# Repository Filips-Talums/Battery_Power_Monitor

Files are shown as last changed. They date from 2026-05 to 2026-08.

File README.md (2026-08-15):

# Supply_Power_Monitor

## Overview

Battery_Power_Monitor is an ESP32-based DC inline power monitor designed to measure voltage, current, and power while a DC source powers an external load.

The system is designed to support a wide range of DC input sources from 6 V to 12 V and aims to act as a compact monitoring tool for electronics development and testing.

---

## Project Goals

Through this project I aim to learn:

- PCB design using KiCad
- Circuit testing and calibration
- ESP32 microcontroller development
- Embedded systems programming using C++
- Professional project documentation using GitHub
- Power monitoring and sensor integration

---

## Components Used

- ESP32 Development Board
- INA226 Power Monitoring Sensor
- 128x64 I2C OLED Display
- 6 V buck-boost converter module for powering the ESP32 from a 6–12 V input
- Screw Terminals
- Electrolytic and Ceramic Capacitors
- Fuse Protection

---

## How It Works

An external DC power source between 6 V and 12 V is connected through screw terminals.

The input power is split into two sections:

- A regulated 6 V supply powers the ESP32 and OLED display
- The main power line passes through the INA226 current and voltage sensor before reaching the external load

The INA226 measures:

- Bus Voltage
- Current Draw
- Power Consumption

The ESP32 processes this data and displays the measured values on the OLED screen.

The device is intended to help monitor power usage, diagnose faults, and test small electronics projects safely.

---

## System Diagram

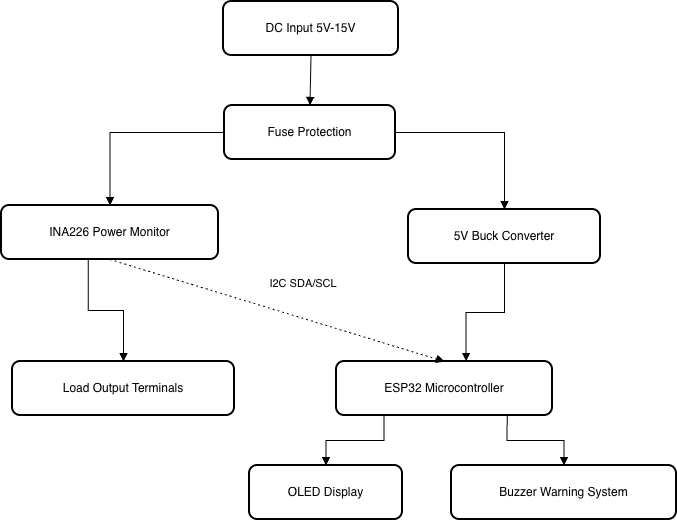
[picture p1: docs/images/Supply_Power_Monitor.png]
System Diagram


### Power Flow

```text
DC Input (6 V - 12 V)
        │
        ├──→ LM2596S Buck Converter (5 V)
        │          │
        │          └──→ ESP32 ──→ OLED Display
        │                        └──→ Buzzer Warning
        │                        └──→ LED Warning
        └──→ Fuse Protection
                   │
                   └──→ INA226 Power Monitor
                                │
                                └──→ Load Output
```
## Current Status

The breadboard prototype is now working. The ESP32 successfully reads bus voltage and shunt voltage from the INA226 power monitoring sensor and displays voltage, current, and power on the OLED display.

Initial voltage calibration has been completed using a multimeter. The raw INA226 bus voltage reading was found to be consistently higher than the multimeter reading, so a software correction factor was applied.

Current calculation has been implemented using the INA226 shunt voltage and the R100 0.1 Ω shunt resistor. Initial current testing has been carried out using resistor loads and a multimeter. The monitor initially under-read current slightly, so a current correction factor was added in software. Further load testing with higher-current loads is still planned.

* Project requirements defined
* Main components selected
* System block diagram completed
* PlatformIO project created
* INA226 integrated with the ESP32
* OLED display integrated and tested
* Live voltage, current and power measurements displayed
* Voltage readings calibrated against a multimeter
* Current readings tested and calibrated using multiple resistive loads
* Breadboard prototype completed and tested
* Circuit transferred from breadboard to perfboard
* LM2596 buck converter configured to provide a regulated 5 V supply
* Schottky diode and polyfuse protection added
* LED and buzzer fault indicators added
* ESP32 mounted using removable female headers
* Initial perfboard wiring faults identified and repaired
* Perfboard prototype powered and operating successfully
* Breadboard and perfboard software versions organised separately
* Manufacturing process, testing and troubleshooting documented
* Project images added to the documentation

## Project Images

### Top View — Arduino Load at 8.76 V

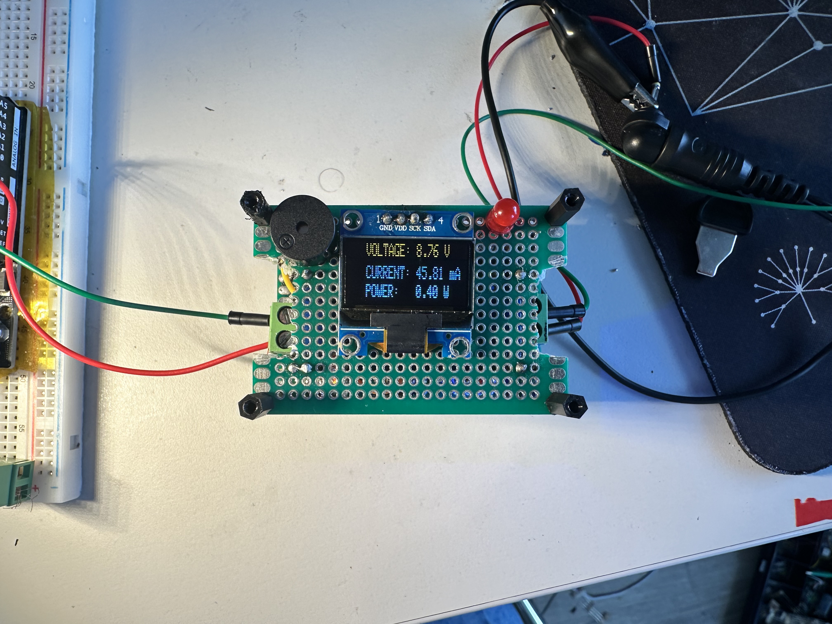
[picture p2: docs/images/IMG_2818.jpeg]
Top view of the power monitor testing an Arduino load at 8.76 V


### Isometric View — Power Monitor and Arduino Load

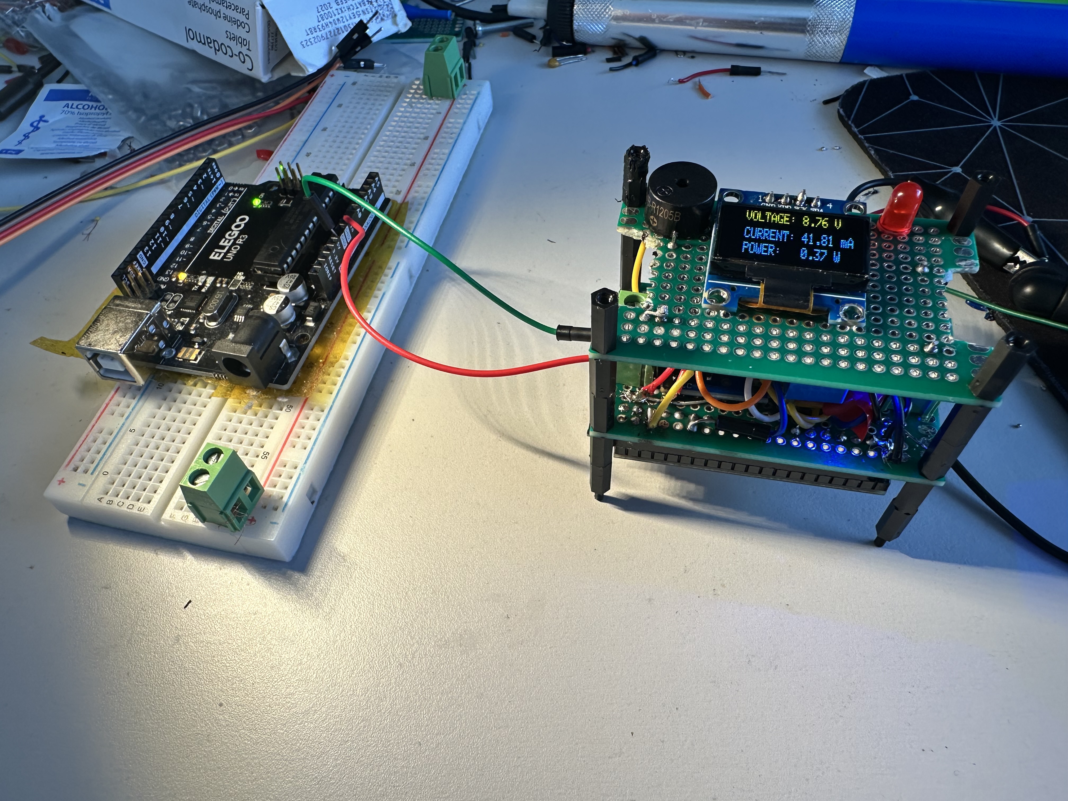
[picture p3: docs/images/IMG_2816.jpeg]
Isometric view showing the power monitor and Arduino load


### Side View of the Device

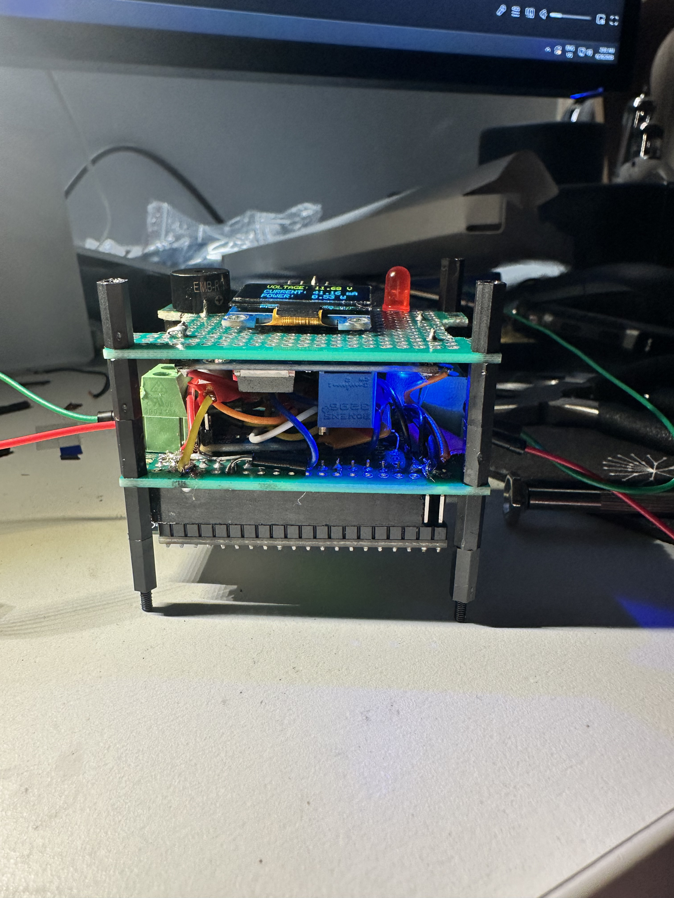
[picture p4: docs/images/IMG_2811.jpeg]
Side view of the completed power monitor prototype


### Isometric View — Arduino Load at 11.68 V

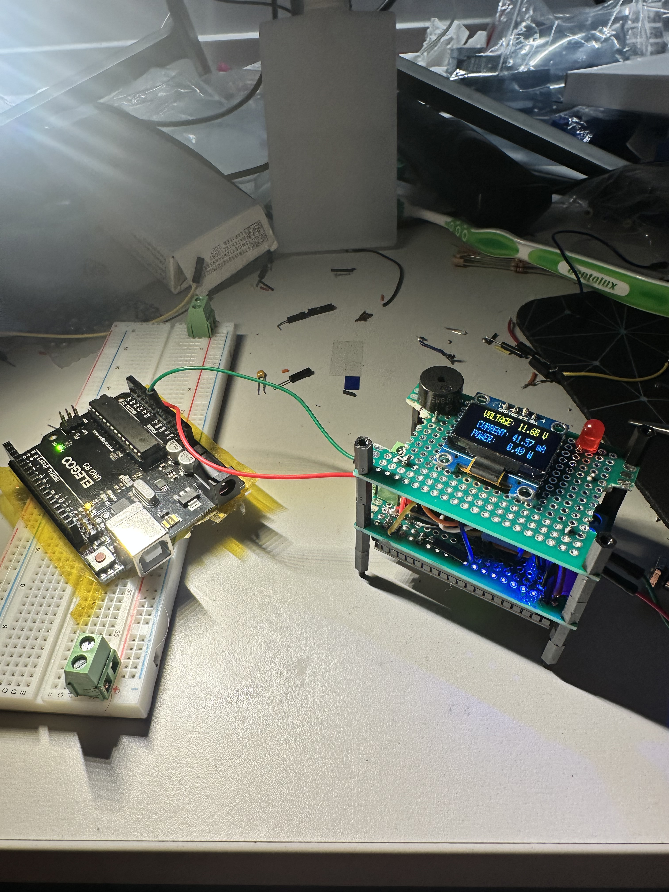
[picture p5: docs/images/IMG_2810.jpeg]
Isometric view of the Arduino and power monitor displaying 11.68 V


### Isometric View — Arduino Load at 8.78 V Input

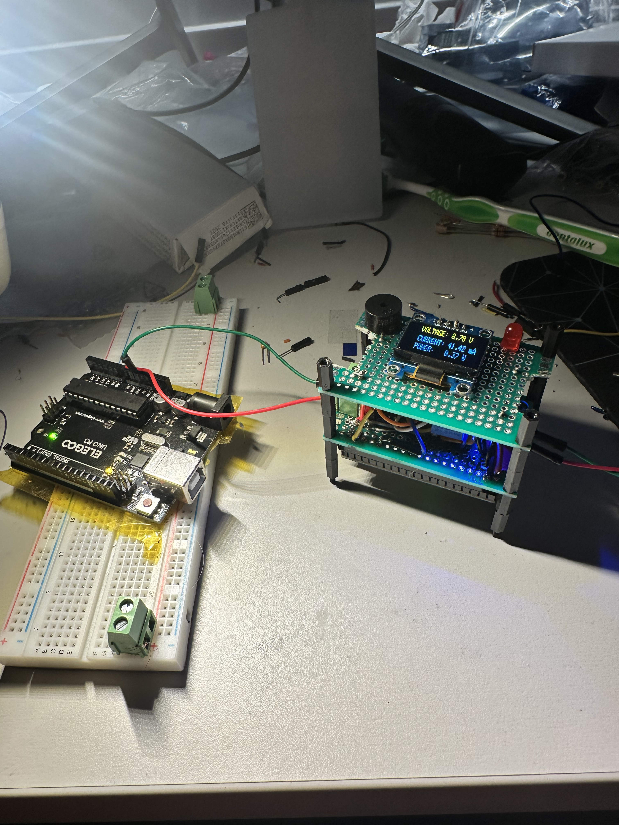
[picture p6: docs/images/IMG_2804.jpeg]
Isometric view of the Arduino load and power monitor at an 8.78 V input


## Next Steps

* Complete extended testing with higher-current loads
* Confirm the 2 A warning system under a controlled load
* Design a custom PCB in KiCad
* Add suitable connectors and component footprints
* Design or manufacture an enclosure
* Perform final accuracy, thermal and reliability testing

## Software

- [Breadboard Prototype V1](software/breadboard-prototype-v1/)

- [Perfboard Prototype V2](software/perfboard-prototype-v2/)

## Project Documentation

- [Design Process](Design_Process.md)
- [Hardware Files](hardware/)
- [Software](software/)
- [Examples](examples/)
- [Learning Notes](docs/learning/)

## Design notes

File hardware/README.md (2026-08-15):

# Hardware

- [KiCad](kicad/) contains PCB design sources, earlier board versions, manufacturing outputs, and recovery material.
- [Schematics](schematics/) contains exported circuit diagrams.
- [Datasheets](datasheets/) contains component reference documents used by the project.

All historical design and manufacturing files are retained so that earlier project stages remain reproducible.

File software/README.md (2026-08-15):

# Software

The software is kept in project-stage folders so working historical checkpoints remain available:

- [Breadboard prototype V1](breadboard-prototype-v1/) is the stable calibrated breadboard firmware.
- [Perfboard prototype V2](perfboard-prototype-v2/) is the firmware associated with the perfboard build.
- [`platformio/`](platformio/) contains the earlier `Supply_Power_Monitor` and `Supply_Power_Monitor_TEST` PlatformIO projects.
- [`pseudocode.txt`](pseudocode.txt) contains the early software design outline.

Each firmware project is self-contained and should be opened from its own directory in PlatformIO.

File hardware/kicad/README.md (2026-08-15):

# KiCad Designs

This directory preserves the project's KiCad design history and manufacturing files:

- `Power_Monitor_V1/` contains the first PCB design.
- `Power_Monitor_V2/` contains the version 2 project, its libraries, 3D model, and tracked recovery material.
- The top-level `Power_Monitor_V2.1.kicad_*` files contain the later version 2.1 board project files.
- `PCB_V2_PRINTING/` and `PCB_V2_PRINTING.zip` contain version 2 manufacturing outputs.

Recovery and historical files are intentionally retained. Open the version matching the project stage you want to inspect.

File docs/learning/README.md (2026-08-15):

# Learning Notes

- [Learning PlatformIO](Learning_PlatformIO.md) records PlatformIO project structure, mock sensor testing, and lessons learned.
- [ESP32 Notes](ESP32_Notes.md) is a placeholder for future ESP32 notes.
- [INA226 Research](INA226_Research.md) is a placeholder for future INA226 research.

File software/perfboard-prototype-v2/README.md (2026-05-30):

# Breadboard Prototype V1 Software

This folder contains the PlatformIO software used for the first working breadboard prototype of the DC inline power monitor.

## Purpose

The software reads bus voltage and shunt voltage from the INA226 power monitoring sensor using the ESP32. Current is calculated manually using the R100 shunt resistor value, and power is calculated using voltage multiplied by current.

The measured voltage, current, and power values are displayed on a 0.96 inch 128x64 I2C OLED display.

## Hardware Used

- ESP32 development board
- INA226 power monitoring module with R100 0.1 Ω shunt resistor
- 0.96 inch 128x64 I2C OLED display
- LM2596S step-down buck converter
- Resistor loads for current testing
- Breadboard wiring

## Features

- Reads INA226 bus voltage
- Reads INA226 shunt voltage
- Calculates current manually using the shunt resistor value
- Calculates power manually using voltage × current
- Displays voltage, current, and power on the OLED display
- Displays low current values in milliamps
- Includes voltage correction based on multimeter calibration
- Includes current correction based on resistor load testing

## Calibration

During voltage testing, the raw INA226 bus voltage reading was consistently higher than the multimeter reading. A software correction factor was applied to make the displayed voltage match the measured voltage more closely.

Current testing was carried out using resistor loads and a multimeter. The monitor initially under-read current slightly, so a current correction factor was added in software.

Current is calculated using:

```text
Current = Shunt Voltage / Shunt Resistance
```

## Current Status

This version is confirmed working on the breadboard prototype. It should be treated as the stable calibrated software checkpoint before adding extra features such as warning outputs, improved display layout, buttons, or PCB-specific changes.

## Next Steps

- Test with higher-current loads
- Add overvoltage warning logic
- Add overcurrent warning logic
- Improve OLED display layout
- Move the circuit from breadboard to a soldered prototype or PCB

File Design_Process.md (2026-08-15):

# Design Process

## 1. Project Aim

The aim of this project is to work as a power monitor between the source voltage and load, being an external project. The monitor will display useful information like the incoming voltage, current and the power the load is taking in. It'll be designed to be compact and be an addition to my electronics workbench where i can use it to create and diagnose, if needed, future projects.

## 2. Problem / Need

When testing small electronics projects, it can be difficult to know how much current the circuit is drawing from the power source. If a project draws more current than expected, it may indicate a wiring fault, short circuit, damaged component, or incorrect design. In many cases, the problem is only noticed after a component becomes hot, behaves incorrectly, or fails completely.

This project is designed to make voltage, current, and power usage visible in real time. By placing the monitor between the power source and the external load, faults can be spotted earlier and diagnosed more quickly. This should reduce the chance of damaging components and make testing small electronics projects safer and easier.

## 3. Design Requirements

### Compact Design

The device should be small enough to be easily stored, carried, and used on a desk or workbench without taking up too much space.

### Stable Physical Design

The device should sit securely on a table during use. It should not be easily knocked over or pulled off the table when wires are connected.

### Easy-to-Read Display

The voltage, current, and power readings should be clearly shown on the OLED display. The user interface should be simple and readable from normal viewing angles while working at a desk.

### Accurate Readings

The device should measure voltage, current, and power with enough accuracy for testing small electronics projects. The readings should be compared against a multimeter during testing to check for error.

### Safety Features

The circuit should include basic protection features such as a fuse or polyfuse to protect against excessive current. Reverse polarity protection should also be considered to reduce the risk of damaging the device if the input is connected incorrectly.

### Quick Usability

The device should be simple to use. The user should be able to connect a power source and external load using screw terminals, power the device on, and quickly view live voltage, current, and power readings.

### 3.1 Input Voltage Range

The device should support a DC input voltage range of **5 V to 12 V**, which suits small electronics projects such as microcontroller circuits, sensors, LEDs, and low-power modules.

A **5 V buck-boost converter** is required to provide a stable 5 V supply for the ESP32 and OLED display, even when the input voltage varies between 5 V and 12 V. This is needed because a standard buck converter may not reliably output 5 V when the input is also 5 V.

If an adjustable buck-boost converter is used, the adjustment screw or control point should be accessible without needing to disassemble the device. This allows the output voltage to be checked or adjusted during setup and maintenance.

### 3.2 Current Range

The first iteration of the power monitor will be designed for small electronics projects with a current range of **0–3 A**. This range is suitable for low-power sensor circuits, microcontroller projects, LED modules, and small single-board computer projects.

A 3 A limit gives more headroom than a 1 A design, as some devices can draw short current spikes during startup or when extra peripherals are connected. For example, a Raspberry Pi or similar board may draw around 1 A or more depending on the connected accessories and workload.

The fuse/polyfuse and INA226 module should be selected so they can safely support the chosen **0–3 A** current range.

### 3.3 Measurements Required

The power monitor is required to display **voltage**, **current**, and **power** in real time.

- **Voltage** should be displayed in volts (V).
- **Current** should be displayed in amps (A), or milliamps (mA) for lower current readings.
- **Power** should be displayed in watts (W).

Power will be calucalted using the measured voltage and current

Power = Current x Voltage

The displayed values should use a suitable number of decimal places so the readings are clear and easy to understand.

### 3.4 Display Requirements

The display should be clear and readable from a normal working distance when the device is being used on a desk or workbench. The readings should also be visible from different viewing angles so the user does not need to position themselves directly above the display.

The user interface should be simple and easy to understand at a glance. Voltage, current, and power readings should be clearly labelled with their correct units, such as V, A, mA, and W.

### 3.5 Safety Requirements

The power monitor should include basic safety features to reduce the risk of damage to the monitor itself and the connected load.

- **Overcurrent protection:** A fuse or resettable polyfuse should be used on the input/load path. This protects the circuit if the external load draws too much current or if a short circuit occurs.

- **Reverse polarity protection:** The input should include protection against the power source being connected the wrong way around. This reduces the risk of damaging the ESP32, INA226, OLED display, and connected load.

- **Overvoltage warning:** The INA226 should be used to detect if the input voltage is above the specified operating range. If the voltage exceeds the safe limit, the ESP32 should display a warning on the OLED screen.

- **Accurate readings:** The device should provide reliable voltage and current readings so the user can identify abnormal current draw or voltage issues before damage occurs.

### 3.6 Size and Usability Requirements

The device should be compact enough for easy storage, transport, and use on a desk or workbench. The target size is approximately the size of three 9 V batteries placed together.

The internal layout should be designed to use space efficiently. Modules may be stacked or arranged in layers inside the chassis if this does not cause overheating, wiring strain, or difficulty accessing key components.

The device should have a stable physical design so it does not move around easily when wires are connected. The weight should be distributed evenly across the chassis to reduce the risk of the device being pulled or knocked off the table during use.

The device should be simple to use and operate as a plug-and-play monitor. It should be powered from the same input source being measured, so no separate external power supply is required for the ESP32, OLED display, or sensor circuit.

## 4. System Overview

### 4.1 Block Diagram

```text
6–12 V DC Input
        │
        ▼
Input Screw Terminals
        │
        ├──→ Buck/Buck-Boost Converter → 5 V → ESP32
        │                                      │
        │                                      ├──→ OLED Display
        │                                      ├──→ LED Warning
        │                                      └──→ Buzzer Warning
        │
        └──→ INA226 Power Sensor → Load Output Terminals → External Load
                         │
                         └── I2C Data → ESP32
```
### 4.2 Power Flow

The DC input first enters the device through the input screw terminals. From there, the input power is split into two paths.

The first path goes to the buck-boost converter. The buck-boost converter provides a stable 5 V output, which is used to power the ESP32, OLED display, LED, and buzzer.

At the same time, the second path goes through the INA226 power monitoring sensor and then continues to the load output terminals. The external load is connected to these output terminals. This allows the INA226 to measure the voltage supplied to the load and the current drawn by the load.

### 4.3 Data Flow

The INA226 power monitoring sensor sends voltage and current readings to the ESP32 using I2C communication. The ESP32 receives this data, processes it in software, and calculates the power value in watts.

The processed data is then sent to the OLED display, where the voltage, current, and power readings are shown to the user. The ESP32 can also control the LED and buzzer based on the measured values, such as activating a warning if the voltage or current goes outside the safe operating range.

## 5. Component Selection

### 5.1 ESP32-WROOM-32E Microcontroller

The ESP32-WROOM-32E was chosen because it gives the project enough processing power and input/output pins for the power monitor without making the design too expensive or complicated.

Compared to an Arduino Uno, the ESP32 has a much faster clock speed and a dual-core processor. This allows it to read data from the INA226 sensor, calculate voltage, current, and power values, update the OLED display, and control the warning LED and buzzer without slowing down.

The ESP32 also uses I2C communication, which is useful because both the INA226 sensor and OLED display can share the same SDA and SCL lines. This reduces wiring and keeps the circuit layout simpler.

Although the project does not currently require wireless features, the built-in WiFi and Bluetooth are useful advantages of the ESP32. They allow the design to be expanded later for data logging, wireless monitoring, or sending readings to a phone or computer.

Overall, the ESP32 was selected because it is low cost, powerful, widely supported, and suitable for real-time monitoring in this project

### 5.2 INA226 Power Monitoring Sensor

The INA226 power monitoring sensor was selected because it is capable of accurately measuring both bus voltage and current while remaining suitable for the scale of this project. It provides a good balance between performance, cost, and simplicity without being unnecessarily complex.

The INA226 can measure bus voltages up to 36 V and current levels depending on the value of the shunt resistor used on the module. The module purchased is rated for up to approximately 3 A, however the exact current limit will depend on the installed shunt resistor. As the specifications of the included shunt resistor were not provided in the product listing, the exact rating will be confirmed once the module arrives.

If required, the shunt resistor can be replaced using soldering equipment to better suit the current range and accuracy requirements of the project.

### 5.3 OLED Display

A 0.96 inch 128x64 I2C OLED display was chosen to show the live voltage, current, and power readings. The display only requires four connections: VCC, GND, SDA, and SCL, making it simple to connect to the ESP32.

The 128x64 resolution provides enough space to display all key readings at the same time, allowing the user to quickly check the power source and load behaviour during testing.

### 5.4 Buck Converter

The input voltage for the project is expected to vary between 5 V and 15 V. As the ESP32 requires a stable 5 V supply, a buck converter is needed to safely reduce and regulate the input voltage. Supplying the ESP32 with a voltage above its rated input could damage the microcontroller and other components.

The LM2596S DC-DC Step-Down Buck Converter Module was selected because it is suitable for the voltage range required in this project while remaining simple to prototype with during development. The module can accept an input voltage between approximately 4.5 V and 40 V and regulate it down to a lower stable output voltage.

The module also includes the main supporting components required for switching regulation already mounted on the PCB, making it easier to integrate into a breadboard prototype before designing a custom PCB later in development.

Although the module is commonly advertised as capable of supplying up to 3 A, this value is treated as a maximum module rating rather than the expected continuous operating current within this project. The ESP32, OLED display, INA226 module, and buzzer require significantly less current, meaning the LM2596S provides sufficient overhead for stable operation.

For this project, the buck converter will be adjusted and verified using a multimeter before connecting the ESP32 to ensure a stable 5 V output is supplied to the circuit safely and reliably.

LM2596 Datasheet:
https://www.ti.com/lit/ds/symlink/lm2596.pdf

### 5.5 Fuse / Polyfuse

A 2 A resettable polyfuse is included to protect the circuit from excessive current caused by faults such as short circuits or wiring mistakes. If the current exceeds the safe operating limit, the polyfuse temporarily increases in resistance to reduce current flow and automatically resets once it cools down.

The polyfuse helps prevent components from failing, PCB traces from burning, and wires from overheating during fault conditions within the circuit.

A 2 A limit was selected as it matches the approximate safe operating range of the LM2596 buck converter used in the project while still providing protection for the circuit.

### 5.6 Capacitors

Capacitors are included to improve voltage stability and reduce electrical noise within the circuit.

A 330 µF electrolytic capacitor is placed in parallel between the input voltage line and ground close to the buck converter input. This helps smooth sudden voltage dips and provides extra stability before the voltage is regulated down to 5 V.

0.1 µF ceramic capacitors are placed between the VCC and GND pins of the ESP32, INA226 module, and OLED display. These capacitors act as local decoupling capacitors and help reduce high-frequency noise caused by switching and sudden current changes.

The electrolytic capacitor is used for bulk voltage smoothing, while the ceramic capacitors are used for high-frequency noise filtering.

### 5.7 Diodes

A diode is placed at the voltage input to protect the circuit if the supply voltage is connected with reverse polarity. If the positive and negative terminals are connected the wrong way around, the diode helps prevent current from flowing through the circuit in the wrong direction, reducing the risk of damage to the buck converter, ESP32, and other components.

A Schottky diode is suitable for this part of the circuit because it has a lower forward voltage drop than a standard silicon diode. This means less voltage is lost across the diode, allowing more of the input voltage to reach the buck converter.

The diode selected should be able to handle the expected input voltage range of up to 15 V and the chosen current range of approximately 2 A.

1N5822 schottky diode chosen

### 5.7 Input and Output Terminals

Screw terminals will be used if a PCB is manufactured as they provide a simple and reliable method of connecting input and output wires. They also allow wires to be easily removed or replaced without soldering, making the system more interchangeable and easier to test.

A 5 mm pitch screw terminal was selected as it is commonly available and capable of handling voltages and currents far above the requirements of this project, typically up to approximately 250 V and 10 A depending on the model used. This provides significant headroom while also allowing the same terminals to be reused in future electronics projects.

## 6. Circuit Design

Inital Circuit Desing:

(fig.0: Image of revision 0 circuit design to be implemented on a breadboard)

Modified with a shared I2C bus between OLED and INA226 Modules

(fig.1: Image of revision 1 circuit design to be implemented on a breadboard)

### 6.1 Input Power Path

The power source is connected to a 1x2 screw terminal. From the positive input terminal, the track passes through the reverse polarity protection diode and the 2 A polyfuse before reaching the VIN+ input of the buck converter. The negative input terminal is connected to the common ground of the circuit.

A 330 µF electrolytic capacitor is placed in parallel between the input voltage line and ground, close to the buck converter input. This helps smooth the input voltage and reduce voltage dips before regulation.

0.1 µF ceramic capacitors are placed between the VCC and GND pins of the ESP32, INA226 module, and OLED display to reduce high frequency electrical noise and interference. These capacitors are positioned as close as possible to the power pins of each component to improve voltage stability and reduce the effect of sudden current spikes within the circuit.

### 6.2 Load Measurement Path

The load measurement path begins at the protected input voltage line after the reverse polarity diode and polyfuse. This line connects to the IN+ pin of the INA226 module. The current then passes through the INA226 shunt resistor and exits through the IN- pin, which connects to the output screw terminal and then to the external load.

The INA226 measures the voltage drop across its shunt resistor to calculate the load current. The VBUS pin is connected to the IN+ side of the measurement path so that the INA226 can also measure the bus voltage being supplied to the load.

The INA226 communicates with the ESP32 using I2C. The SDA and SCL pins connect to ESP32 GPIO 27 and GPIO 14 respectively. The ALERT pin connects to ESP32 GPIO 26 and can be used to trigger a warning if the measured values exceed a set limit.

A possible future improvement would be to use the ALERT pin as part of an automatic protection system. If an overcurrent or fault condition is detected, the ESP32 could use a transistor, MOSFET, or relay driver circuit to disconnect the load as an additional safety feature.

### 6.3 ESP32 Power Supply

The ESP32 receives a stable 5 V supply from the LM2596 buck converter. The 330 µF capacitor is placed near the buck converter input to help smooth voltage dips before regulation.

A stable 5 V supply is required because voltage drops or electrical noise could cause the ESP32 to reset, lose communication with the INA226, cause OLED display errors, or display unreliable readings.

The onboard voltage regulator on the ESP32 development board reduces the 5 V input to 3.3 V. This 3.3 V supply is used to power the INA226 module, OLED display, LED, and suitable low-power output components.

All components share a common ground connection, which provides a common voltage reference for stable communication and accurate measurement through the INA226.

### 6.4 I2C Communication

Figure 0 shows the I2C communication connections between the ESP32, INA226, and OLED display.
The following GPIO outputs are used:     
        
        INA226 + OLED
        - SDA = GPIO19
        - SCL = GPIO18
        
         INA226 
        - ALERT = GPIO26

### 6.5 GPIO Outputs

The following GPIO Outputs used:

         BUZZER
        - Signal Pin = GPIO22
         LED
        - VCC = GPIO23

### 6.6 Display Output

The OLED display is used to show live voltage, current, and power measurements to the user in real time.

The readings are displayed in a simple vertical layout so they can be quickly understood while testing electronics projects on a workbench.

Depending on the measured current range, the displayed units may automatically switch between amps (A) and milliamps (mA) to improve readability and precision.

Example display layout:

```text
|=============================|
|                             |
|       Voltage = 3.3 V       |
|       Current = 1 mA        |
|     PowerDraw = 3.3 mW      |
|                             |
|=============================|
```
### 6.7 Protection and Filtering

The circuit includes several protection and filtering components to improve safety and reliability. A Schottky diode is placed at the voltage input to reduce the risk of damage if the supply is connected with reverse polarity.

A 2 A resettable polyfuse is also used to protect the circuit from excessive current caused by faults such as short circuits or wiring mistakes. If the current becomes too high, the polyfuse increases in resistance and limits current flow until it cools down.

A 330 µF capacitor is placed near the buck converter input to help smooth voltage dips before regulation. Additional 0.1 µF ceramic capacitors are placed close to the ESP32, INA226, and OLED power pins to reduce high frequency noise and improve voltage stability.

## 7. Software Design

[INSERT C++ FILE WHEN FINSIHED]

### 7.1 Sensor Reading

The ESP32 communicates with the INA226 sensor and OLED display using I2C communication. The `Wire.h` library is used to initialise the I2C bus and allow the ESP32 to communicate with connected I2C devices.

I2C allows multiple components to share the same SDA and SCL communication lines. Each device is identified by its own unique I2C address.

For this project, the I2C pins are defined in the I2C Communication section. The bus is initialised using:

```cpp
Wire.begin(19, 18);
```
Commands that will be used to initalise and extract data from the INA226:

- **bool begin()** Used to initalise the class / INA226

- **bool isConnected()** Verifiys if INA226 was foun on the I2C Bus

- **setMaxCurrentShunt()** Sets a Maximum current across the shunt, if exceeeded the Alert pin emmits, later be used to shut of the circuit using a transitor.

- **float getBusVoltage_mV()** Calls the Bus Voltage in mV

- **float getShuntVoltage_mV()** Calls the Shunt Voltage / Voltage drop across the shunt resistor

- **float getCurrent_mA()** Calls the current flwoing through shunt resistor

- **float getPower_mW()** Calls the power which in the library caluclated by (BusV x Current) = Power

- **bool isConversionReady()** Returns a bolean if there is new data ready, used for later iterations of projects as more complicated however more accurate

INA226 library used:
https://github.com/RobTillaart/INA226

### 7.2 Warning / Error Messages

- Overvoltage: If there is a voltage across the shunt resistor > 15 volts, a warning would be displayed on the screen prompting for the Vs to be disconnected before damage occurs.
  
- Undervoltage: If there is a voltage across the shunt resisotr < 5v, a warning would be displayed as the readings can lead to be inaccurate as the esp32then wouldnt be getting the reuiqred voltage as a result

- Overcurrent: If there is over current across shunt resistor above 2 amps itd be displayed on the screen however I do not belive the current would ever reach as the INA226 module would fail as a result of over current howver a fuse would trip if 2 amps is exceeded.

- Sensor Not Found: Using the isConnected() function from the INA226 module, if the module is dead or not connected properly this would show on the screen 

- I2C Communication Error: If communication between the ESP32 and connected I2C devices fails, an error message would be displayed on the OLED screen. This could occur due to loose wiring, incorrect SDA or SCL connections, incorrect device addresses, or a disconnected component. The ESP32 can detect this if the INA226 or OLED no longer responds on the I2C bus.

- Weak Battery: Using (inital voltage - load voltage) / inital voltage * 100 if that is above 12.5 % a warning for a weak battery would be shown

- Measurement Overflow: If the measured voltage or current exceeds the measurable range of the INA226, the readings may become inaccurate or invalid. A warning message would be displayed to indicate that the sensor has exceeded its operating limits and the load or supply should be disconnected immediately.

## 8. Prototype Testing

### 8.2 Buck Converter Test & Calibration

- [Results](docs/testing/buck_converter_test.md)

### 8.3 INA226 Test & Calibration

- [Results](docs/testing/ina226_test.md)

### 8.5 OLED Display Test

- [Results](docs/testing/oled_display_test.md)

Circuit_BB_PreBuzzerLED

### 8.1 Breadboard Test

The completed breadboard prototype marked an important milestone in the project. The earlier component planning and circuit design produced a working result, with the ESP32 and OLED display powering on successfully and showing voltage, current and power data measured by the INA226.

### 10.4 Wiring and Connection Issues

The selected diode had legs that were too thick to fit securely into the breadboard. Crocodile clips were therefore used to connect it temporarily during testing.

Apart from this issue, the breadboard wiring was straightforward and no major connection problems occurred during this stage of prototyping. This allowed the project to progress to the next phase: transferring the circuit onto perfboard.

The buzzer and LED fault indicators were not included in the breadboard prototype because they had initially been overlooked. These features were added later during the perfboard build.

### 10.5 Final Breadboard Design

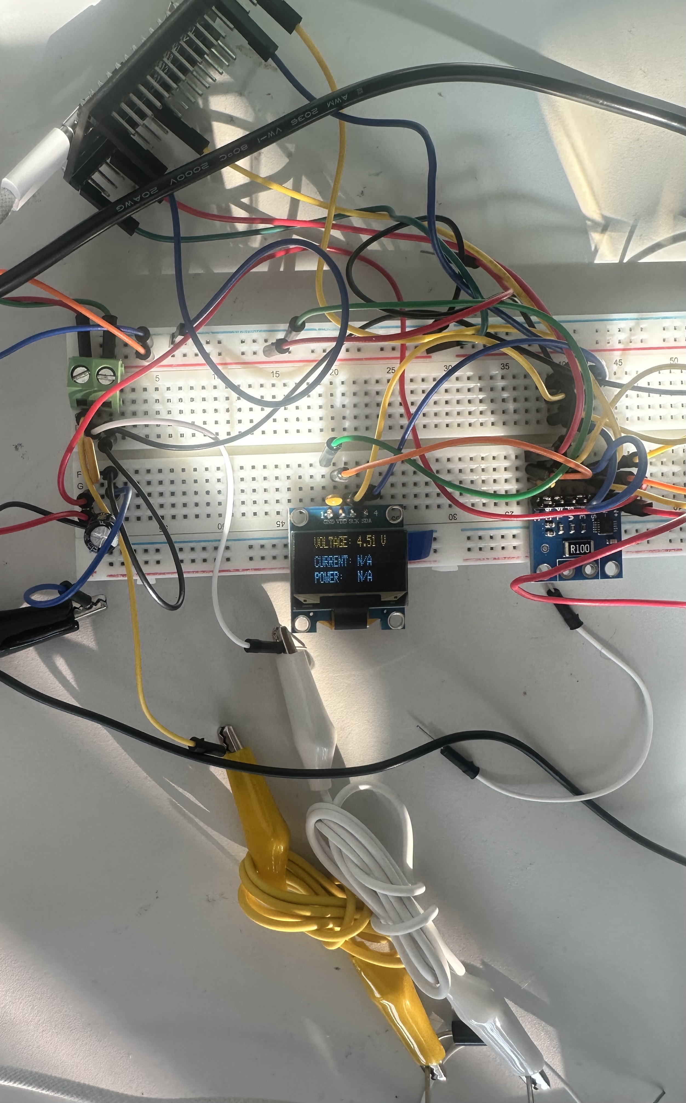
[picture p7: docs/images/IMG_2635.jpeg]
Breadboard build


## 11. Perfboard Prototype

### 11.1 Design

A perfboard kit containing several different board sizes was purchased for the prototype. Initially, the range of sizes appeared useful. However, it quickly became clear that the mounting holes would only align correctly when matching perfboards of the same dimensions were used.

The kit contained five different sizes. Three were too small to accommodate the required header footprint, while another was unnecessarily large. A suitable intermediate size was selected and proved to be a good fit for the final arrangement.

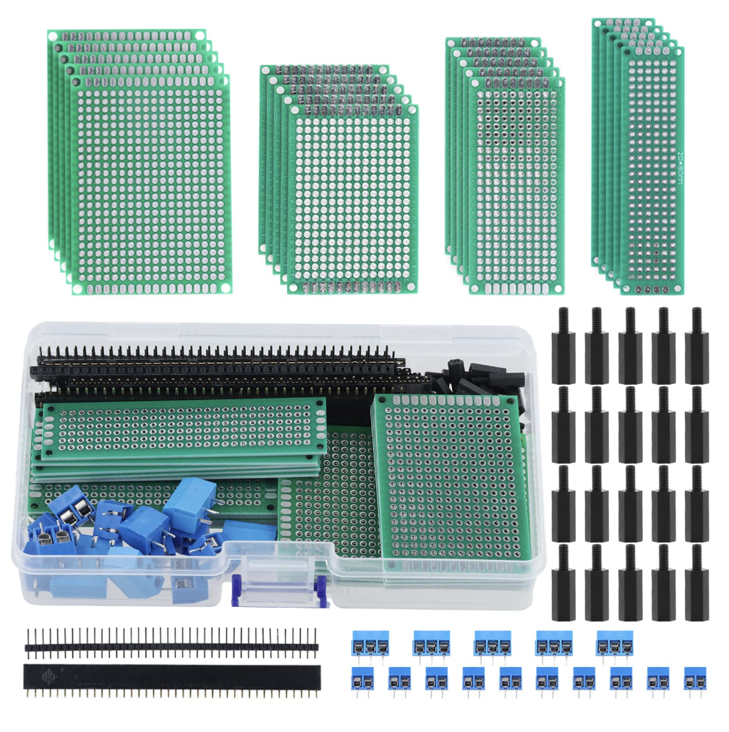
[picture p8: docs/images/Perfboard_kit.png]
Perfboard Kit


The final design used two layers of perfboard mounted together with the nylon hex spacers supplied in the kit. This structure allowed the device to be easily disassembled and reassembled for troubleshooting, repairs and future modifications.

Female header sockets were used to mount the ESP32 rather than soldering it permanently. This allowed the ESP32 to be removed and reused later when the custom PCB version is designed and manufactured. The remaining components were soldered permanently onto the perfboards.

The track layout was not planned in enough detail before soldering. The main consideration was wire length, rather than the full routing of power, ground and signal connections.

Solid-core jumper wires were initially intended for the build. However, the supplied wires were unsuitable because solder did not adhere properly to the conductor material. Alternative wire was therefore required to complete the connections reliably.

### 11.2 Manufacturing

The input and output screw terminals were mounted first. The protection components were then added in series with the positive input connection, beginning with the Schottky diode followed by the polyfuse.

Where possible, the component legs were used as conductive tracks to reduce the amount of additional wiring required. The ground terminals of the input and output connectors were linked using a section of jumper wire.

The buck converter was mounted next on a separate perfboard positioned near the centre of the assembly. This location allowed it to reach the ESP32 power pins without excessive wire routing.

Once the buck converter had been mounted and connected, the first checkpoint test was carried out. A power supply was connected to the input screw terminal, and the indicator LED on the buck converter illuminated, confirming that power was reaching the module.

The input and output voltages were then measured with a multimeter. The adjustment potentiometer was used to set the converter output to approximately 5 V before the ESP32 was connected.

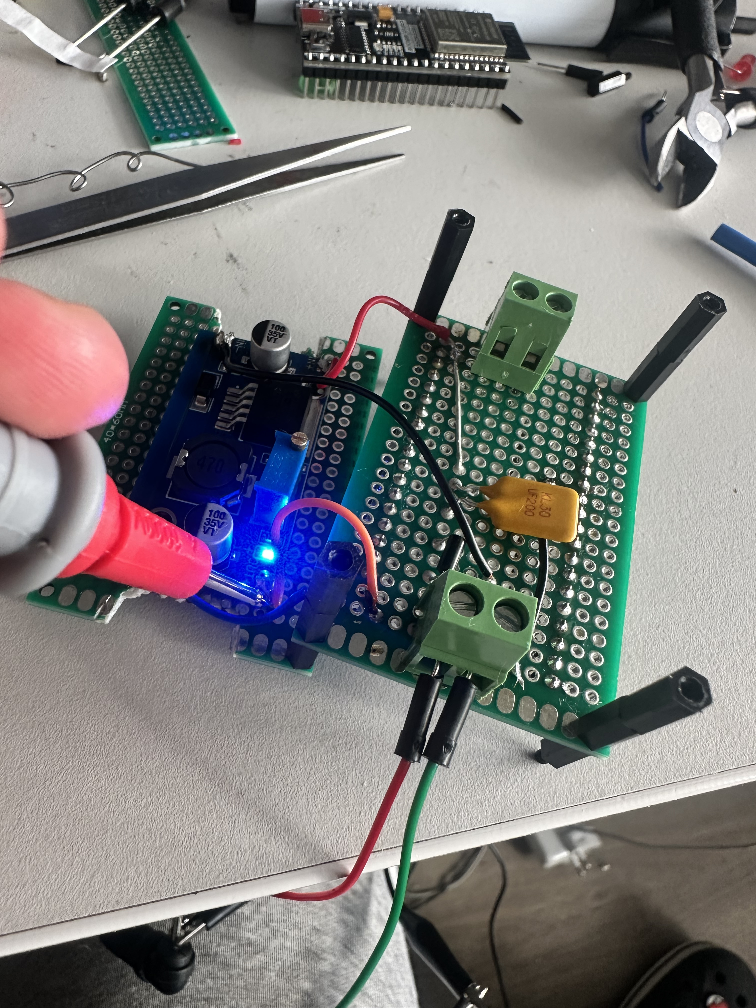
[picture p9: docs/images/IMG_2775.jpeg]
Buck converter powered


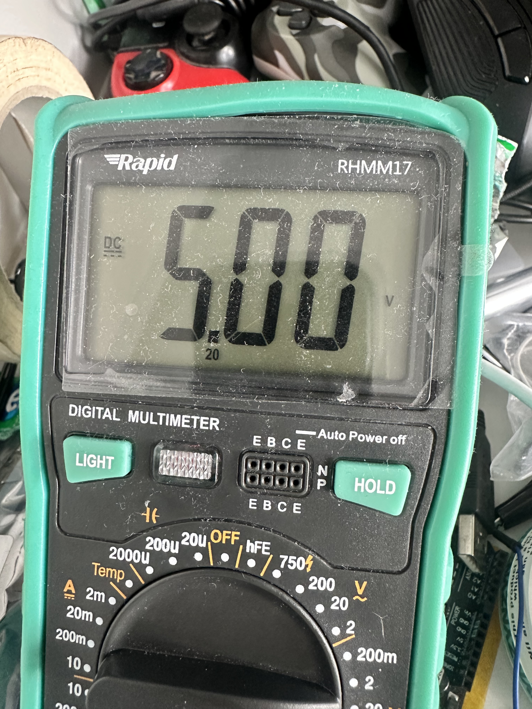
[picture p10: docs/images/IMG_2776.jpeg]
Buck converter output test


The INA226 module was then mounted on the opposite side of the same perfboard as the ESP32. Several connection methods were used depending on the available space. These included wrapping stripped jumper wire around header pins before soldering and bridging adjacent pads with solder where the pins were positioned close together.

The INA226 was not tested immediately after installation, which was an oversight. Construction instead continued with the OLED display.

The display was mounted near the top of the second perfboard. Jumper wires were then soldered between the display and the required ESP32 power and I2C connections.

At this stage, the main hardware components had been installed and the project moved on to full circuit testing.

### 12.3 Problems and Solutions

One design issue was that the screw terminals were positioned underneath the board. This made access more awkward during wiring and testing and should be improved in a future version.

During the first full power-up test, the ESP32 was inserted into its socket and the device was connected to the power supply. However, nothing powered on.

A short circuit was suspected because the buck converter indicator LED illuminated when the ESP32 was removed but turned off when the ESP32 was inserted.

An ineffective troubleshooting method was initially attempted by partially inserting the ESP32 into the socket to determine when the buck converter LED switched off. This did not identify the fault and risked creating additional connection problems.

A more systematic approach was then used. The wiring was checked with a multimeter in continuity mode, which revealed a short circuit between the 3.3 V rail and ground. The cause was a small stray strand of copper wire bridging two connections.

Once the copper strand was removed, the short circuit was cleared and the circuit powered on successfully.

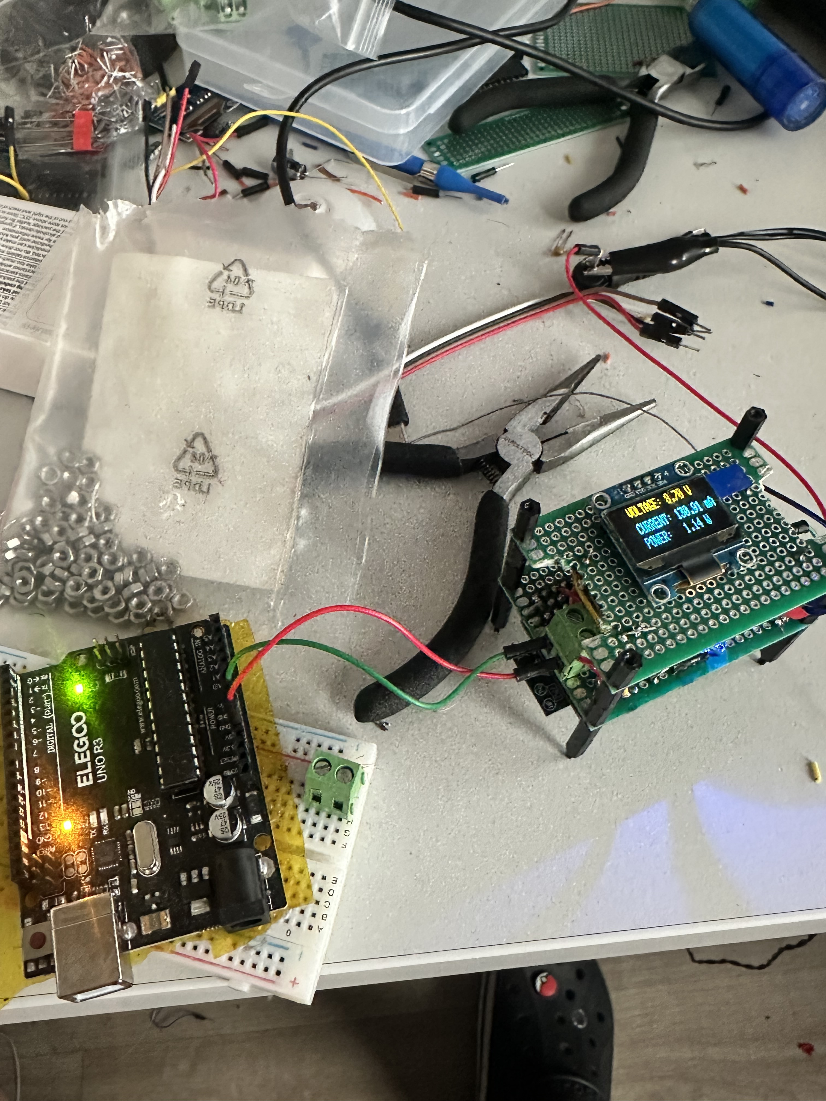
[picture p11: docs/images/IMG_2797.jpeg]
Initial working prototype


### 11.4 Final Perfboard Design

Prototype image 1

Prototype image 2

Prototype image 3

Prototype image 4

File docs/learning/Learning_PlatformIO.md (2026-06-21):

# Learning PlatformIO

During the software development aspect of the project, an alternative to Arduino IDE came to light: PlatformIO on Visual Studio Code.

It proved to compile and upload code in a much more streamlined manner compared to Arduino IDE, which displayed everything in a friendly and bare-bones manner. However, PlatformIO began to bring light to the real-world embedded systems project design process, showing how the software is not one big `.ino` file but rather multiple modules based on header and source files that compile together. A benefit of this already demonstrated during development is its easy interchangeability and expandability.

## Understanding Multi-File Projects

Initially, at the start of this project, it was required to understand what each pin on the ESP32 does and which pins would be required for this project. This was done using the components that were available at hand. However, through consultation with ChatGPT, the method of having one long file would quickly become a bottleneck if projects were to become bigger and more advanced.

A solution to this was using header and source files. Through previous experience of digging through config files of a game to change the resolution or FOV when not available through the menu, it was easier than if the code itself had to be changed by the developers. So, a multi-file system was adopted which consisted of a config file containing constant values including GPIO output/input pins, limit parameters for voltage, current and voltage drop, shunt value, and the module’s address, where it can all be easily called at any point without multiple lines having to be changed.

Initially, it was intimidating, but after understanding that the header file is used to set the names of the callable functions while the source file contains the script of the functions themselves, it all fell into place in how much more organised a project can be.

## Mock Sensor Testing

The modules required for this project were ordered from AliExpress. As the parts were being sourced from China, they would take time to arrive. Sitting idle was not an option, so the next step was to prepare the software side of the project before the modules arrived.

Instead of waiting for the INA226 module to return real data, the code was temporarily adjusted to return constant float values for voltage and current. The power value was then calculated from these fake values. This allowed the program structure, serial output, and PlatformIO setup to be tested without the physical sensor connected.

After the code was adjusted, an attempt was made to compile it. As expected, it failed at first. One mistake was that the INA226 library uses `getBusVoltage()` rather than `getVoltage()`, which caused compilation errors. Once this was fixed, the code compiled successfully.

The program was then uploaded to the ESP32 and tested using the Serial Monitor. The fake voltage, current, and power values printed correctly, confirming that the multi-file structure, function calls, and serial communication were working before the real sensor arrived.

## Serial Monitor Test Result

The Serial Monitor showed the expected values:

Voltage (V): 9.00

Current (A): 0.52

Power (W): 4.68

This confirmed that the test code was performing as expected. The next step is to implement the OLED display once it arrives.

## Problems Encountered

During testing, several errors were encountered while setting up the multi-file structure. One issue was a linker error caused by function names not matching between the header file, source file, and main file. This showed that declarations in `.h` files must match the function definitions in `.cpp` files exactly.

Another issue was caused by defining non-constant values inside the config header file. As this file was included in multiple source files, the same variable was created more than once, causing linker errors. This was fixed by using constant values for configuration settings such as the INA226 address.

The final issue encountered was the Serial Monitor baud rate. The output first appeared as unreadable characters because the monitor speed did not match the baud rate set in the code. This was fixed by adding `monitor_speed = 115200` to the `platformio.ini` file, matching the value used in `Serial.begin(115200)`.

This testing process helped explain the difference between compiling and linking, and showed why modular code needs to be structured carefully.

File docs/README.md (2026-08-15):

# Documentation

Project documentation is grouped here by purpose:

- [Learning notes](learning/) contains research and development notes.
- [Testing](testing/) contains component tests, calibration work, and results.
- [Images](images/) contains photographs and illustrations used throughout the documentation.

The overall design record remains in the top-level [Design Process](../Design_Process.md).

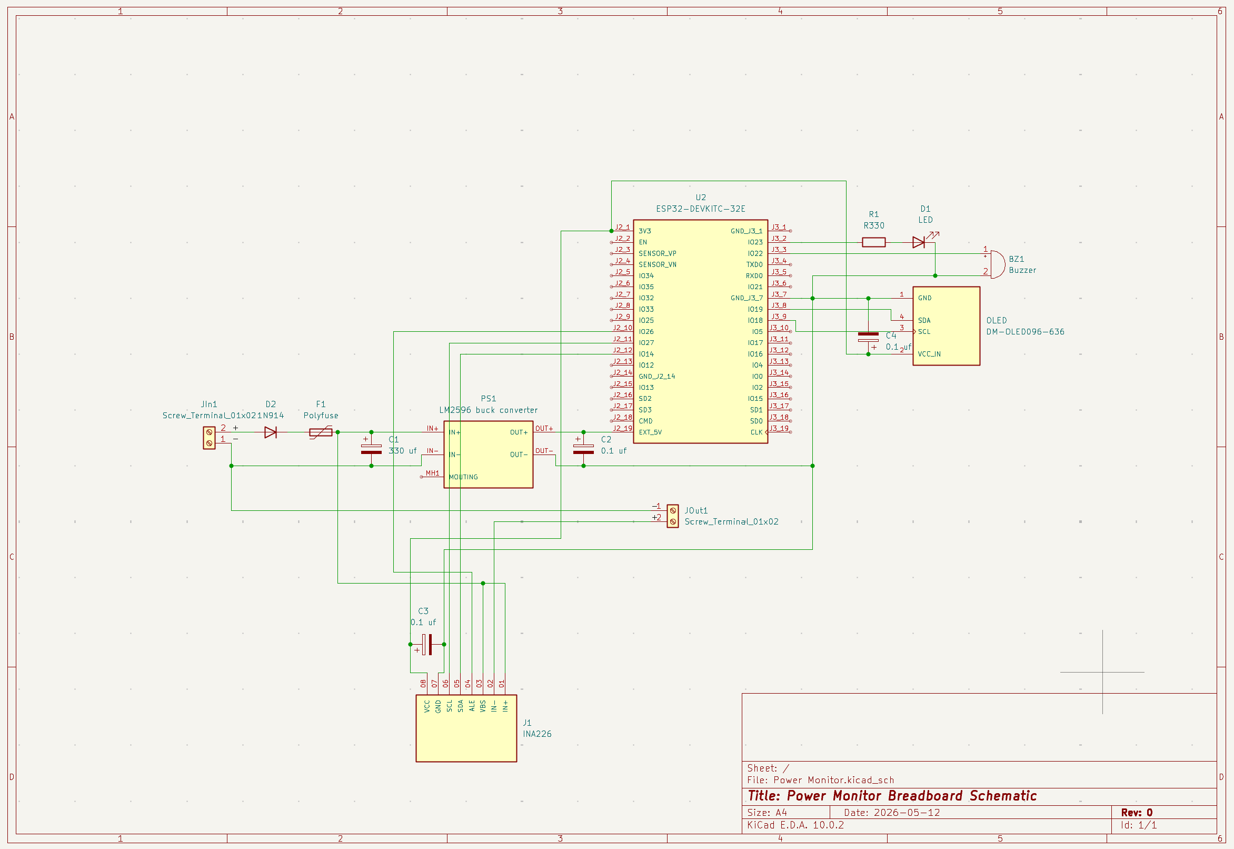
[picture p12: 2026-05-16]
hardware/schematics/Power_Monitor_Breadboard_Schemeatic_0.png

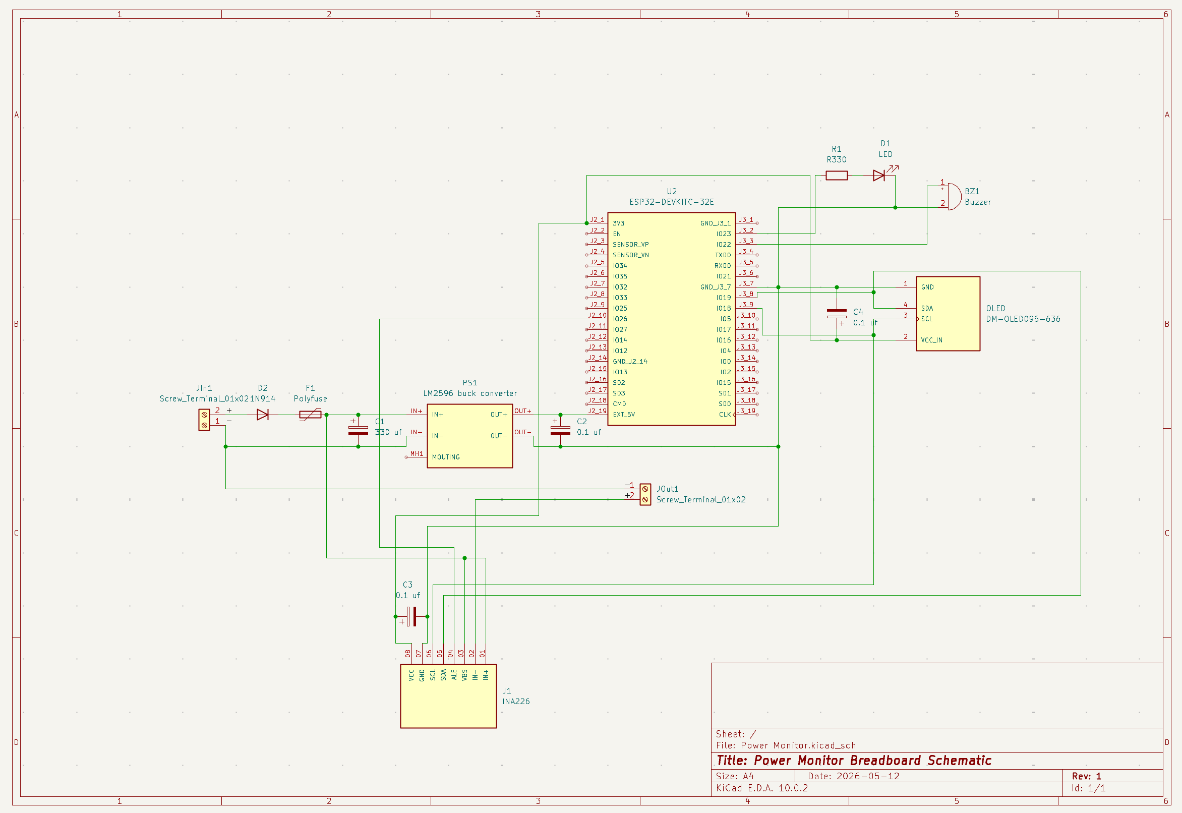
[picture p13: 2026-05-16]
hardware/schematics/Power_Monitor_Breadboard_Schemeatic_1.png

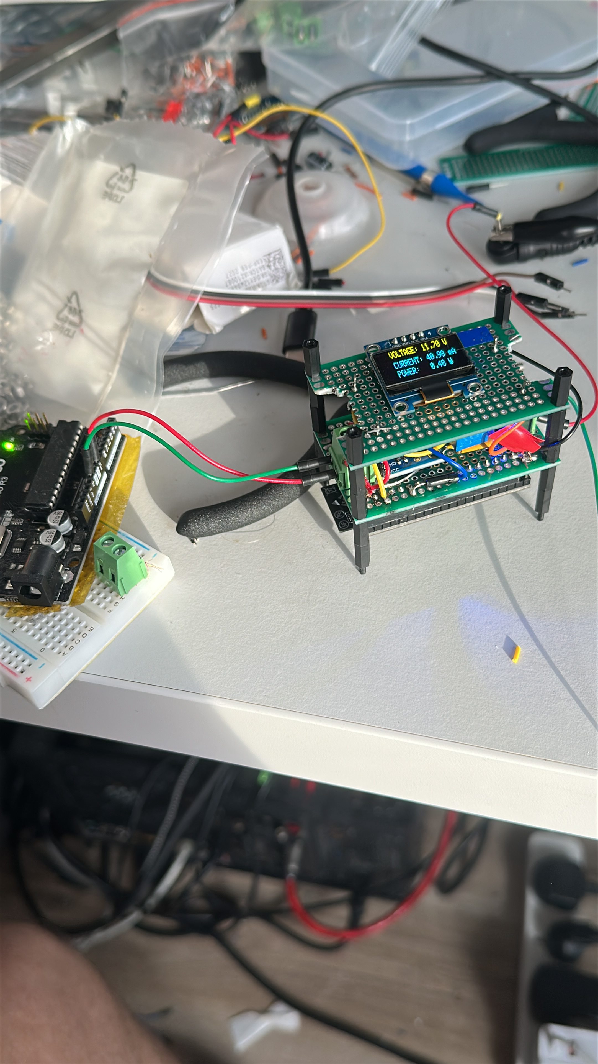
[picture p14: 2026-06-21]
docs/images/43884CEB-D7D4-4211-9E3B-0C1ADC69D1E4.JPG

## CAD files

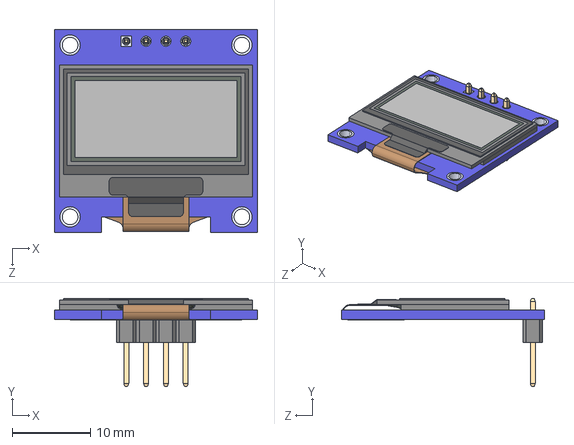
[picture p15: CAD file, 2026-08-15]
hardware/kicad/Power_Monitor_V2/_restore_backup_2026-08-08T14-32-29-726/3d_models/DM-OLED096-636.step
26.0 x 11.3 x 26.0 mm
DM-OLED096-636_Module
DM-OLED096-636_Panel

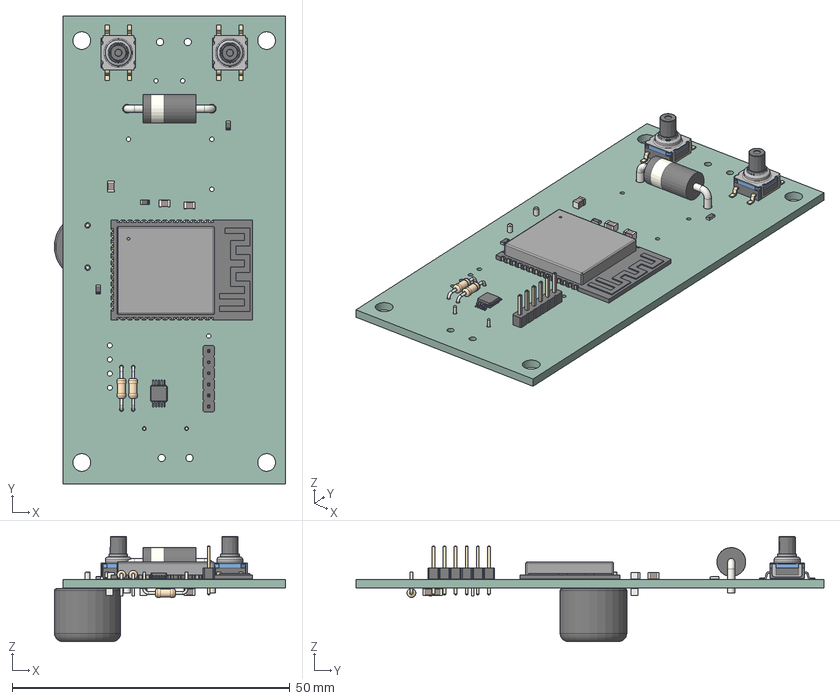
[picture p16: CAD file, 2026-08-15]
hardware/kicad/Power_Monitor_V2/PCB.step
41.6 x 84.2 x 18.9 mm
R_0603_1608Metric x 3
SW_Push_1P1T_NO_CK_KSC6xxG x 2
C_0805_2012Metric x 6
D_DO-201AD_P15.24mm_Horizontal
R_Axial_DIN0204_L36mm_D16mm_P762mm_Horizontal x 3
PinHeader_1x06_P200mm_Vertical
TSSOP-10_3x3mm_P0.5mm
ESP32-S3-WROOM-1
Buzzer_12x95RM76
Power_Monitor_V2_PCB

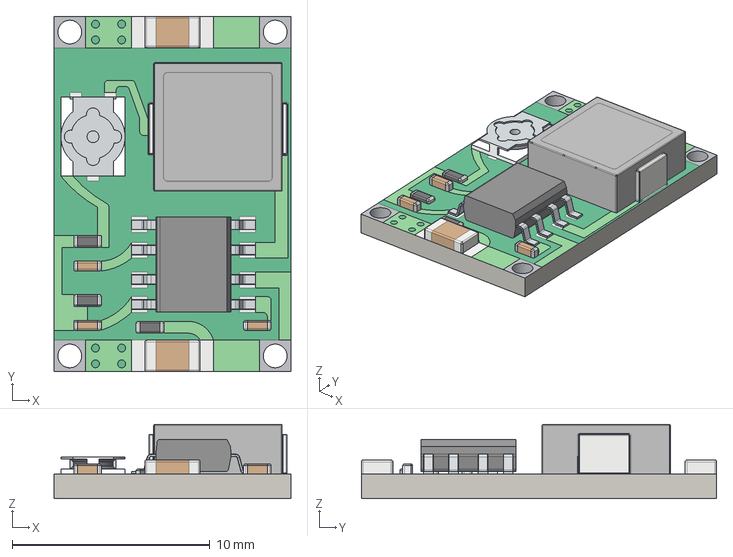
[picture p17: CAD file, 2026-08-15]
hardware/kicad/Power_Monitor_V2/_restore_backup_2026-08-08T14-32-29-726/3d_models/MIni - 360.step
12.0 x 18.0 x 3.75 mm

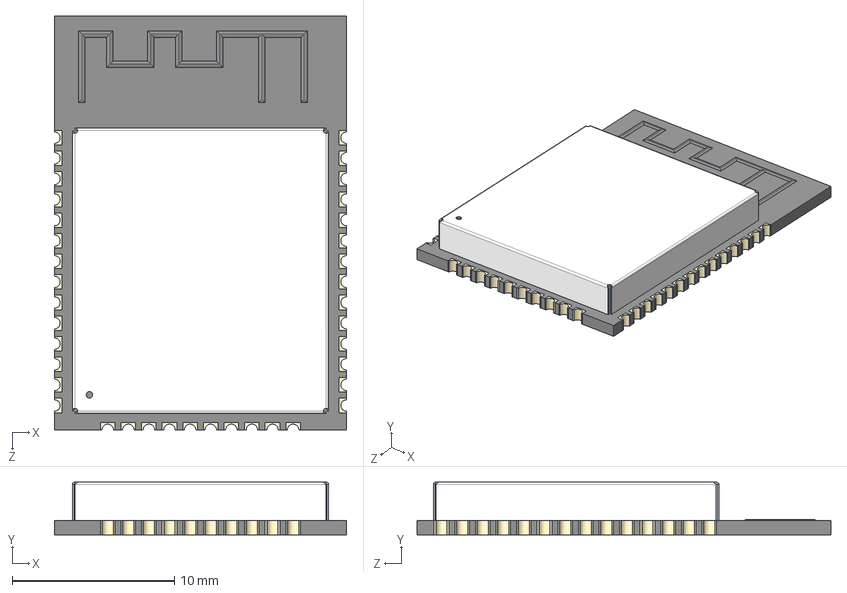
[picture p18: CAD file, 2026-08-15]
hardware/kicad/Power_Monitor_V2/_restore_backup_2026-08-08T14-32-29-726/3d_models/ESP-WROOM-32.step
18.0 x 3.25 x 25.5 mm

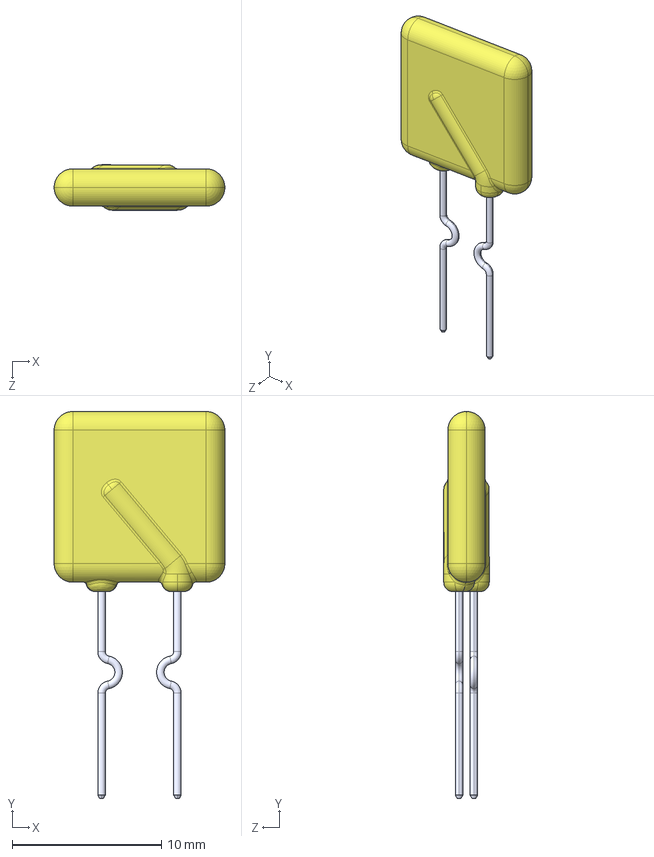
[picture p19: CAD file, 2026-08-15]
hardware/kicad/Power_Monitor_V2/_restore_backup_2026-08-08T14-32-29-726/3d_models/Polyfuse_2A.step
11.4 x 25.9 x 3.05 mm

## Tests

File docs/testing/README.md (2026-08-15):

# Testing Documentation

- [Buck converter test](buck_converter_test.md)
- [INA226 sensor test](ina226_test.md)
- [OLED display test](oled_display_test.md)
- [Testing results](testing_results.md)

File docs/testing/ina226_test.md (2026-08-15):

# INA226 Sensor Test

## Wiring

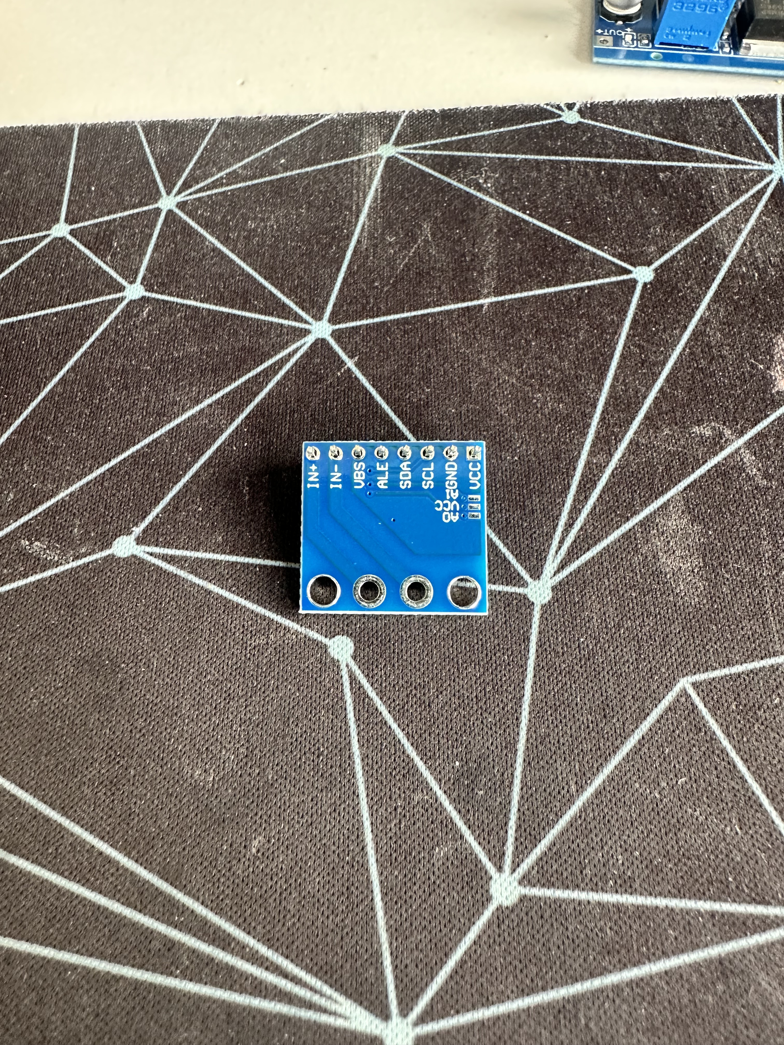
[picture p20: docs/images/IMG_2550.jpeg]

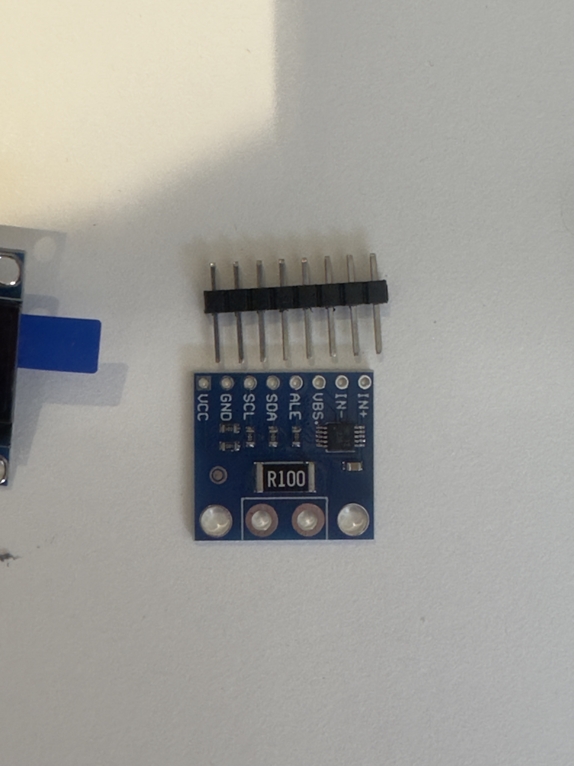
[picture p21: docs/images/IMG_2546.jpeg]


The INA226 module arrived with the header pins unsoldered; therefore, soldering was required before testing could begin. The pin headers were inserted perpendicular to the module and held in position while soldering was performed.

Flux was first applied to each solder pad to improve solder flow and joint quality. A pre-tinned soldering iron was then used to heat both the pin and solder pad before solder was applied to form the joint. If a solder joint appeared dull or uneven, reflow soldering was performed until a smooth and reflective finish was achieved. This process was repeated for all eight pins.

Once soldering was completed, the module was visually inspected to ensure that no solder bridges or poor joints were present before testing began.

## I2C Communication Test

## Get Picture of The I2C found ##

The INA226 module was inserted into the breadboard and connected to the ESP32 using the VCC, GND, SCL, and SDA pins according to the predetermined circuit diagram.

An I2C scanner script was uploaded to the ESP32 to verify communication between the ESP32 and the INA226 module. Once the module was successfully detected on the I2C bus, testing proceeded to voltage measurement verification.

## Testing Procedure (FIX SPELLING)

IMG_2578 IMG_2579
IMG_2581 IMG_2582

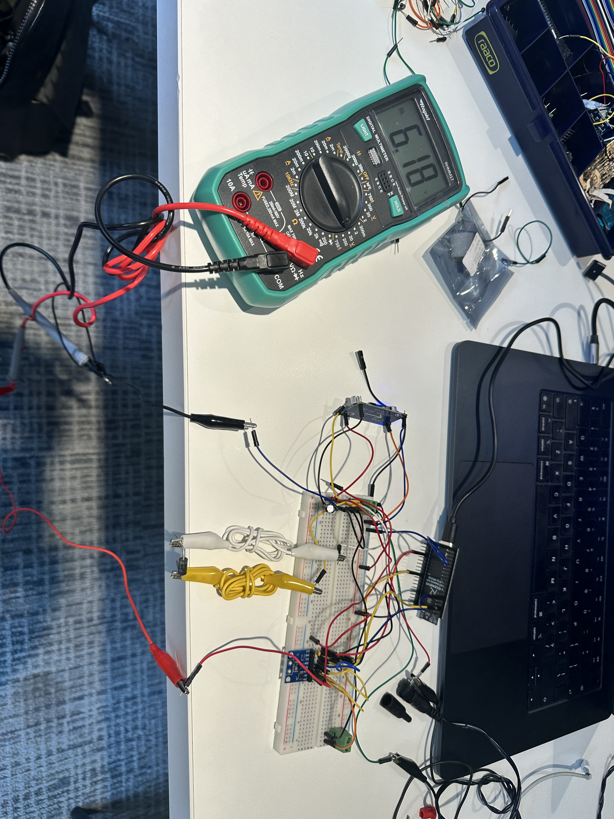
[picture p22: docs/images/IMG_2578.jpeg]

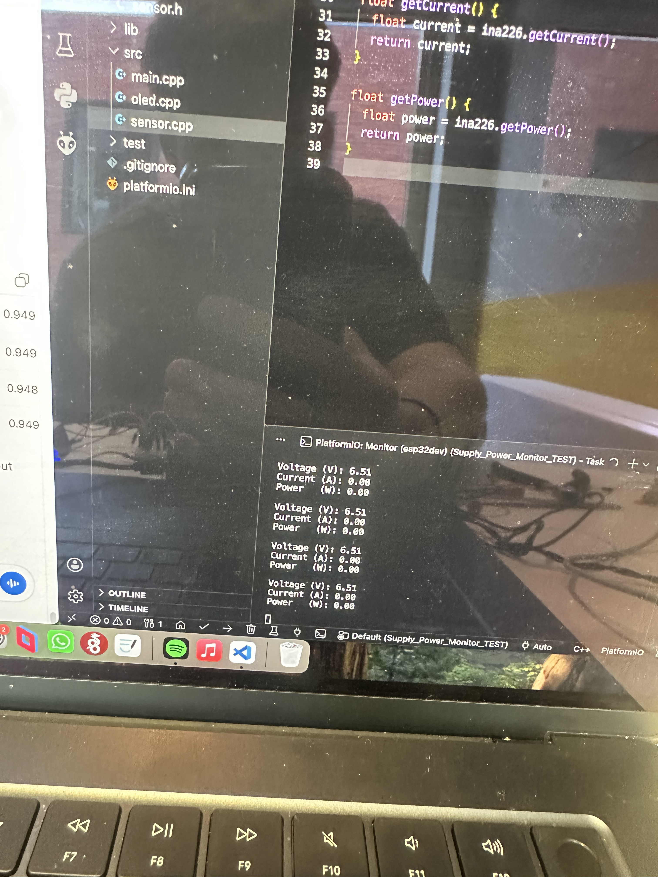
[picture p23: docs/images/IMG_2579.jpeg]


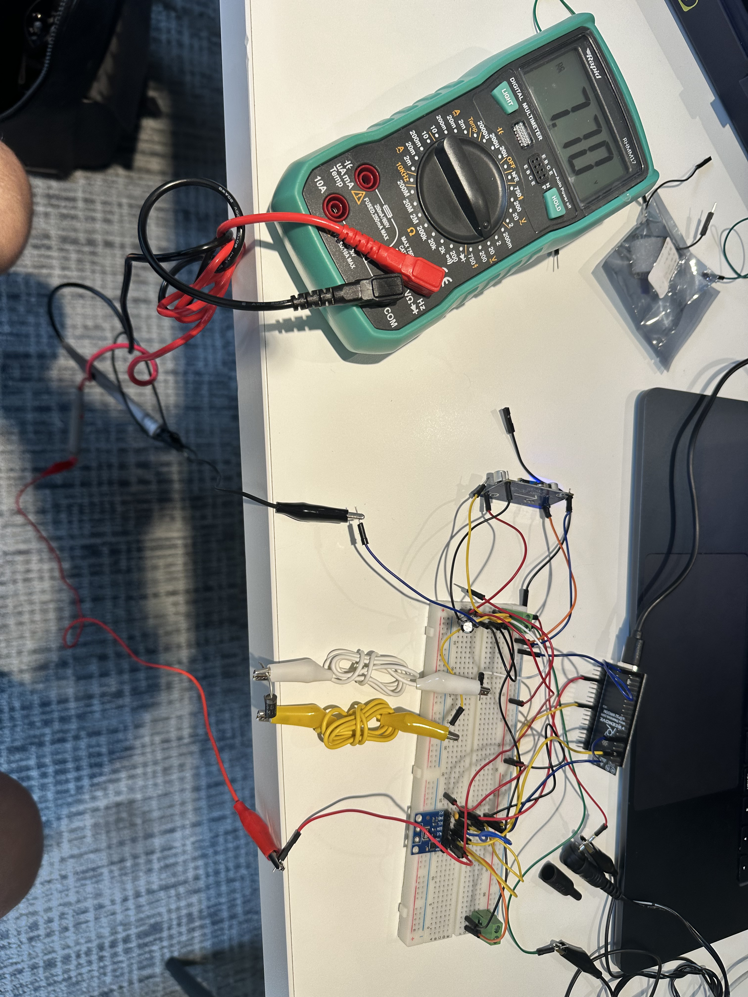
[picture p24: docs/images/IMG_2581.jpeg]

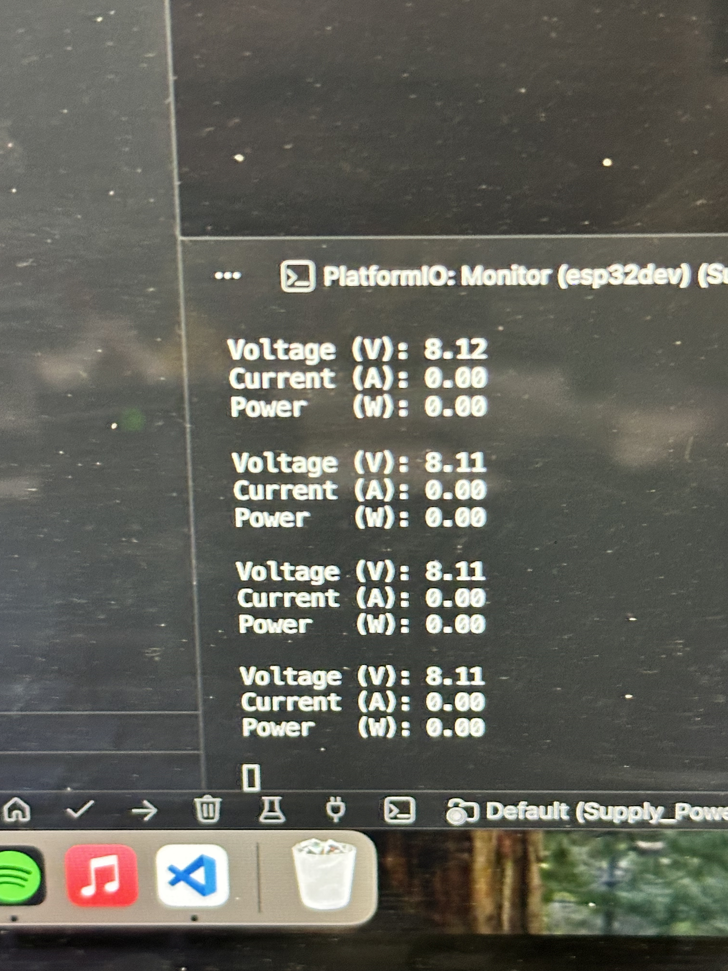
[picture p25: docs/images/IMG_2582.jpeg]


For voltage multimeter in V dc prongs placed on the positive and negatvie terminals of the output screw terminal this data was compared to the INA226 readings in the serial monitor where then a correction factor can be calcultaed if needed.

To verify the current readings jumpers were placed intot the screw terminal then placed on a breadboard where then from the postiive went to the postive probe of multimter and the negative probe when to a known resistor and back to the ground of the output terminal. The multimeter was placed in seiries in current mode. The data was taken and again compared to the serial monitor reading of the INA226 module. Finally the diffreence is claculated and a appropriet correction factor is applied. 

## Voltage Measurement Test

Initially, the onboard 5 V supply from the ESP32 was used as the voltage source, bypassing the buck converter during the first stage of testing. The ESP32 was then flashed with INA226 measurement software to verify that voltage readings could be successfully obtained.

Voltage readings were immediately displayed through the serial monitor; however, the measured values differed slightly from the multimeter readings by approximately 0.5%. To improve measurement accuracy, a correction factor was applied in software before displaying the voltage value. The measured voltage was multiplied by a factor of 0.949, resulting in readings that closely matched those observed on the digital multimeter.

The corrected INA226 voltage readings were then compared against the multimeter readings to verify measurement accuracy before proceeding to further testing.

## Current Measurement Test

A test on the current measurement was done using a constant voltage of 6 V while a varied resistor values used. The multimeter probes where placed between Vout and one leg of resistor while the other went back to Vout ground.

A software correction factor of 1.04 was applied.

## Current Testing Results 

| Resistor Load | Multimeter Current | Raw INA226 Current | Correction Factor |
|---|---:|---:|---:|
| 1 kΩ | 6.13 mA | 5.87 mA | 1.044 |
| 470 Ω | 12.7 mA | 12.2 mA | 1.041 |
| 220 Ω | 26.7 mA | 25.7 mA| 1.039 |
| 100 Ω | 56.8 mA | 54.78 mA | 1.037 |

## Voltage Testing Results

| Test | Multimeter Voltage | Raw INA226 Voltage | Correction Factor |
|---|---:|---:|---:|
| 1 | 12.06 V | 12.71 V | 0.949 |
| 2 | 9.18 V | 9.67 V | 0.949 |
| 3 | 7.70 V | 8.12 V | 0.948 |
| 4 | 6.18 V | 6.51 V | 0.949 |

## Conclusion

One the data measured by the INA226 was verified as accurate the final step in the breadboard design face of the project was to have the oled screen display the data effectivly.

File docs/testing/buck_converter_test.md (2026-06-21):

# Buck Converter Test

## Soldering

When the buck converter was received, it did not include pin headers suitable for breadboard use, therefore jumper cables were soldered directly onto the module connections. The module contains four connection points: IN+, IN−, OUT+, and OUT−.

For organisational and safety purposes, coloured jumper cables were assigned to each connection. A red cable was connected to IN+, a black cable to IN−, an orange cable to OUT+, and a blue cable to OUT−. This reduced the likelihood of wiring errors during testing and assembly.

The colour coding also helped prevent accidental reverse or incorrect connections between the input and output terminals. Incorrect wiring could result in the unregulated input voltage being applied directly to components designed to operate at 5 V, potentially causing permanent damage to the ESP32, OLED display, or other connected components.

The soldering procedure began by inserting the exposed end of a jumper cable through the pad hole on the converter module. The cable was then bent slightly to mechanically anchor it in position before soldering. Flux was applied to improve solder flow and joint quality. A soldering iron set to 330 °C was used to preheat the pad and wire before solder was applied to form the joint. This process was repeated for the remaining three jumper cables.

Once all solder joints were completed, the board was cleaned using 95% isopropyl alcohol to remove excess flux residue and contamination from the surface.

<table align="center">
  <tr>
    <td align="center">
      <br>
      <b>Fig. 1:</b> Top View of Buck Converter<br>
      <sub>LM2596 buck converter - Top View.</sub>
    </td>
    <td align="center">
      <br>
      <b>Fig. 2:</b> Soldering Tools<br>
      <sub>Tools used during soldering.</sub>
    </td>
  </tr>
</table>

## Operation

Initially, when the 9 V supply voltage (Vs) was connected to the IN+ and IN− terminals of the buck converter, the multimeter displayed an output voltage of approximately 8.5 V. This output voltage was adjusted using the onboard trimmer potentiometer. A precision adjustment screwdriver, shown in Figure 3, was used to rotate the potentiometer until the multimeter displayed a stable output voltage slightly above 5 V between the OUT+ and OUT− terminals.

Once the output voltage was verified to be a stable 5.03 V using the multimeter, the buck converter was tested by powering the ESP32 development board from the 9 V source through the converter. The OUT+ and OUT− terminals of the buck converter were connected directly to the 5 V and GND pins of the ESP32 using male-to-female jumper cables.

Immediately after connection, a solid green LED illuminated on the ESP32 development board, indicating that a stable power source was present. The multimeter probes remained connected for approximately one minute to monitor the output voltage and ensure that the converter remained stable under operation. During this observation period, the voltage remained constant, confirming that the buck converter was functioning correctly and was suitable for integration into the main project.

<table align="center">
  <tr>
    <td align="center">
      <br>
      <b>Fig. 3:</b> Adjusting the Buck Converter<br>
      <sub>Adjusting the onboard trimmer potentiometer.</sub>
    </td>
    <td align="center">
      <br>
      <b>Fig. 4:</b> Buck Converter Output Verification<br>
      <sub>Buck converter output verified at approximately 5 V using a digital multimeter.</sub>
    </td>
  </tr>
</table>

## Testing Procedure

To verify the operation of the buck converter across different input voltages, a variable DC power supply was used. The converter was tested with input voltages ranging from approximately 5 V to 12 V.

Testing showed that approximately 4.5 V was the minimum input voltage at which both the buck converter and ESP32 powered on successfully. The maximum available voltage from the variable power supply was 12 V, which was therefore the highest voltage tested. Additional testing using a 15 V supply source will be required to fully verify operation across the intended project voltage range.

## Testing Results Bare 

| Input Voltage - Vin (V) | Output Voltage - Vout (V) | Observation |
|---|---|---|
| 12.03 V | 5.01 V | Stable output voltage |
| 8.99 V | 5.00 V | Stable output voltage |
| 7.64 V | 5.01 V | Stable output voltage |
| 6.10 V | 4.98 V | Stable output voltage |
| 5.13 V | 4.55 V | ESP32 powered on successfully; however, further testing is required with the INA226 power monitor and OLED display connected to determine the minimum stable operating voltage of the system. |

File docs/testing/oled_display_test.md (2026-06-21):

# 0.96-Inch OLED Test

## Wiring

The OLED display arrived without the header pins soldered in place, so the four header pins first had to be attached before the display could be used on a breadboard.

Flux was applied to each solder pad to improve solder flow and joint quality. A pre-tinned soldering iron was then used to heat both the header pin and the solder pad before solder was applied. Any joint that appeared dull, uneven, or poorly formed was reheated until a smooth and reflective finish was achieved. This process was repeated for all four header pins.

Male-to-female jumper wires were then connected between the OLED display and the ESP32.

The connections were:

* SCK/SCL → GPIO 22
* SDA → GPIO 21
* VCC → ESP32 3.3 V
* GND → ESP32 GND

A small test script was uploaded to the ESP32 to display an animated image. This confirmed that the OLED display, solder joints, wiring, and I2C communication were functioning correctly.

The display pins were labelled:

* SCK/SCL
* SDA
* VCC
* GND

## I2C Communication Test

The INA226 module was inserted into the breadboard and connected to the ESP32 using the VCC, GND, SCL and SDA pins according to the predetermined circuit diagram.

An I2C scanner script was uploaded to the ESP32 to verify communication between the ESP32 and the INA226 module. The scanner successfully detected the INA226 at its default I2C address of `0x40`, confirming that the module was powered correctly and communicating with the ESP32.

Once communication had been verified, testing proceeded to the voltage measurement stage.

## Testing Procedure

After all jumper wires had been connected correctly between the ESP32 and the OLED module, a small test script was uploaded to the ESP32.

The script displayed an animation on the OLED screen to verify that the display, wiring and I2C communication were functioning correctly.

The animation was displayed successfully, confirming that the OLED module was operating as intended.

## Conclusion

After confirming that the OLED module was functioning correctly, the next stage of the project involved connecting and integrating all modules into the complete circuit.

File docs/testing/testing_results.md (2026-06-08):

# Testing Results

## Breadboard Prototype Test

The breadboard prototype was tested using a variable DC source, multimeter, INA226 sensor, ESP32, OLED display, and LED load.

## Voltage Calibration

Initial testing showed that the raw INA226 bus voltage reading was consistently higher than the multimeter reading by approximately 5.3%. 

| Test | Multimeter Voltage | Raw INA226 Voltage | Correction Factor |
|---|---:|---:|---:|
| 1 | 12.06 V | 12.71 V | 0.949 |
| 2 | 9.18 V | 9.67 V | 0.949 |
| 3 | 7.70 V | 8.12 V | 0.948 |
| 4 | 6.18 V | 6.51 V | 0.949 |

A software correction factor of 0.949 was applied.

## Current Measurement

A test on the current measurement was done using a constant voltage of 6 V while a varied resistor values used. The multimeter probes where placed between Vout and one leg of resistor while the other went back to Vout ground.

| Resistor Load | Multimeter Current | Raw INA226 Current | Correction Factor |
|---|---:|---:|---:|
| 1 kΩ | 6.13 mA | 5.87 mA | 1.044 |
| 470 Ω | 12.7 mA | 12.2 mA | 1.041 |
| 220 Ω | 26.7 mA | 25.7 mA| 1.039 |
| 100 Ω | 56.8 mA | 54.78 mA | 1.037 |

A software correction factor of 1.04 was applied.

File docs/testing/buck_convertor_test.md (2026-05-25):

# Buck Converter Test

## Soldering

When the buck converter was received, it did not include pin headers suitable for breadboard use, therefore jumper cables were soldered directly onto the module connections. The module contains four connection points: IN+, IN−, OUT+, and OUT−.

For organisational and safety purposes, coloured jumper cables were assigned to each connection. A red cable was connected to IN+, a black cable to IN−, an orange cable to OUT+, and a blue cable to OUT−. This reduced the likelihood of wiring errors during testing and assembly.

The colour coding also helped prevent accidental reverse or incorrect connections between the input and output terminals. Incorrect wiring could result in the unregulated input voltage being applied directly to components designed to operate at 5 V, potentially causing permanent damage to the ESP32, OLED display, or other connected components.

The soldering procedure began by inserting the exposed end of a jumper cable through the pad hole on the converter module. The cable was then bent slightly to mechanically anchor it in position before soldering. Flux was applied to improve solder flow and joint quality. A soldering iron set to 330 °C was used to preheat the pad and wire before solder was applied to form the joint. This process was repeated for the remaining three jumper cables.

Once all solder joints were completed, the board was cleaned using 95% isopropyl alcohol to remove excess flux residue and contamination from the surface.

<table align="center">
  <tr>
    <td align="center">
      <br>
      <b>Fig. 1:</b> Top View of Buck Converter<br>
      <sub>LM2596 buck converter - Top View.</sub>
    </td>
    <td align="center">
      <br>
      <b>Fig. 2:</b> Soldering Tools<br>
      <sub>Tools used during soldering.</sub>
    </td>
  </tr>
</table>

## Operation

Initially, when the 9 V supply voltage (Vs) was connected to the IN+ and IN− terminals of the buck converter, the multimeter displayed an output voltage of approximately 8.5 V. This output voltage was adjusted using the onboard trimmer potentiometer. A precision adjustment screwdriver, shown in Figure 3, was used to rotate the potentiometer until the multimeter displayed a stable output voltage slightly above 5 V between the OUT+ and OUT− terminals.

Once the output voltage was verified to be a stable 5.03 V using the multimeter, the buck converter was tested by powering the ESP32 development board from the 9 V source through the converter. The OUT+ and OUT− terminals of the buck converter were connected directly to the 5 V and GND pins of the ESP32 using male-to-female jumper cables.

Immediately after connection, a solid green LED illuminated on the ESP32 development board, indicating that a stable power source was present. The multimeter probes remained connected for approximately one minute to monitor the output voltage and ensure that the converter remained stable under operation. During this observation period, the voltage remained constant, confirming that the buck converter was functioning correctly and was suitable for integration into the main project.

<table align="center">
  <tr>
    <td align="center">
      <br>
      <b>Fig. 3:</b> Adjusting the Buck Converter<br>
      <sub>Adjusting the onboard trimmer potentiometer.</sub>
    </td>
    <td align="center">
      <br>
      <b>Fig. 4:</b> Buck Converter Output Verification<br>
      <sub>Buck Converter In-Use.</sub>
    </td>
  </tr>
</table>

## Testing Procedure

To verify the buck converter across the voltages specified I used a variable power supply, voltages that will be tested against is 5v - 12v.

With testing was shown 4.5 V Vs is the lowest the power pack can go before the buck converter and the esp32 turns on and the pack max go to 12v whcih is the highest tested, a 15v source is going to have to be sourced to verify it can read up to 15 v

## Testing Results

| Input Voltage - Vin (V) | Output Voltage - Vout (V) | Observation |
|---|---|---|
| 12.03 V | 5.01 V | Stable output voltage |
| 9.13 V | 5.00 V | Stable output voltage |
| 7.64 V | 5.01 V | Stable output voltage |
| 6.10 V | 4.98 V | Stable output voltage |
| 5.13 V | 4.33 V | ESP32 powered on successfully; however, further testing is required with the INA226 power monitor and OLED display connected to determine the minimum stable operating voltage of the system. |

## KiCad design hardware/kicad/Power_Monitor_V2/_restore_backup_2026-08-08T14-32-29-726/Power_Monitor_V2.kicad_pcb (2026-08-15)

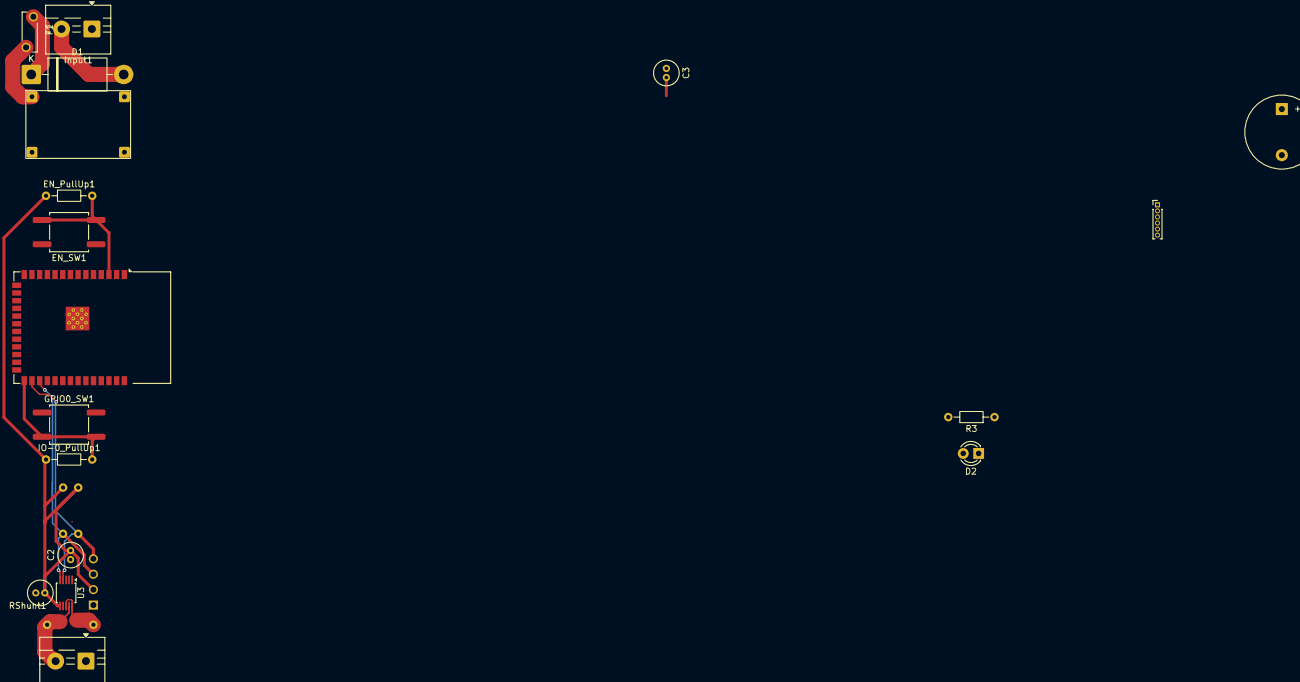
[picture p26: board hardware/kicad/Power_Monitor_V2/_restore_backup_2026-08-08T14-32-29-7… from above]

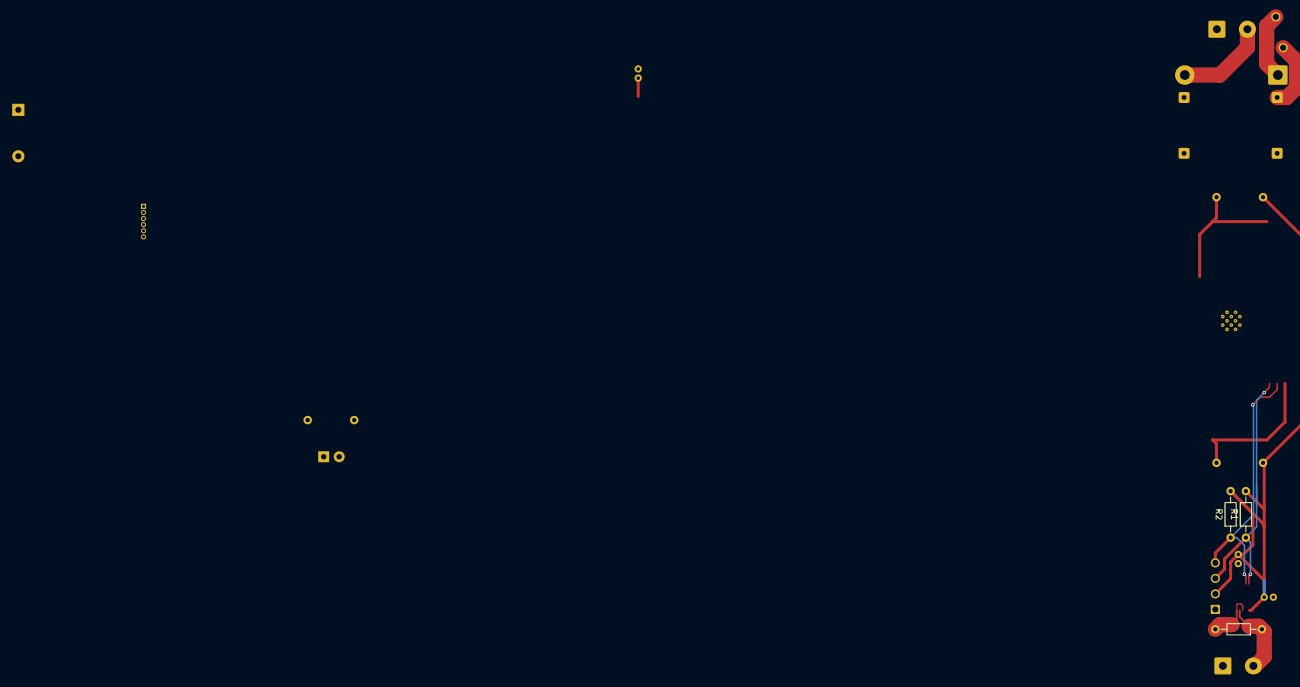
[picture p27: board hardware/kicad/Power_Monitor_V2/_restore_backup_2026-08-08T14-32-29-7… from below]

Board: 2 copper layers, 22 parts (3 on the bottom side), 15 nets.

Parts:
BZ1: Buzzer; Buzzer_12x9.5RM7.6
C1, C2, C3: 0.1uf; C_Radial_D4.0mm_H5.0mm_P1.50mm
D1: 1N5822; D_DO-201AD_P15.24mm_Horizontal
D2: LED; LED_D3.0mm
EN_PullUp1: 10k; R_Axial_DIN0204_L3.6mm_D1.6mm_P7.62mm_Horizontal
EN_SW1: SW_Push; SW_Push_1P1T_NO_CK_KSC6xxG
F1: Polyfuse; Polyfuse_2A
GPIO0_SW1: SW_Push; SW_Push_1P1T_NO_CK_KSC6xxG
IO-0_PullUp1: 10k; R_Axial_DIN0204_L3.6mm_D1.6mm_P7.62mm_Horizontal
Input1: Screw_Terminal_01x02; TerminalBlock_MaiXu_MX126-5.0-02P_1x02_P5.00mm
Output1: Screw_Terminal_01x02; TerminalBlock_MaiXu_MX126-5.0-02P_1x02_P5.00mm
R1, R2: 4.7k; R_Axial_DIN0204_L3.6mm_D1.6mm_P7.62mm_Horizontal
R3: 330; R_Axial_DIN0204_L3.6mm_D1.6mm_P7.62mm_Horizontal
RShunt1: 0.03; R_Axial_DIN0204_L3.6mm_D1.6mm_P7.62mm_Horizontal
U1: mini360_module
U2: ESP32-S3-WROOM-1
U3: INA226; TSSOP-10_3x3mm_P0.5mm
U4: DM-OLED096-636; MODULE_DM-OLED096-636_PINS
U5: PinHeader_1x06_P1.00mm_Vertical

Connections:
+3.3V: C1.1, C2.2, C3.2, EN_PullUp1.1, IO-0_PullUp1.1, R1.2, R2.2, U1.3 (Out+), U2.2 (3V3), U3.6 (VS), U4.2 (VCC_IN), U5.6 (3.3V)
+15V: F1.2, RShunt1.2, U1.1 (In+), U3.8 (Vbus), U3.10 (Vin+)
GNDREF: BZ1.2 (-), C1.2, C2.1, C3.1, D2.1 (K), EN_SW1.2, GPIO0_SW1.2, Input1.1, U1.2 (In-), U1.4 (Out-), U2.1 (GND), U2.40 (GND), U2.41 (GND), U3.7 (GND), U4.1 (GND), U5.1 (GND)
unnamed: BZ1.1 (+), U2.16 (IO46)
unnamed: D1.2 (A), Input1.2
unnamed: D1.1 (K), F1.1
unnamed: D2.2 (A), R3.2
unnamed: Output1.2, RShunt1.1, U3.9 (Vin-)
unnamed: EN_PullUp1.2, EN_SW1.1, U2.3 (EN)
unnamed: GPIO0_SW1.1, IO-0_PullUp1.2, U2.27 (IO0)
unnamed: R2.1, U2.28 (IO35), U3.4 (SDA), U4.4 (SDA)
unnamed: R1.1, U2.29 (IO36), U3.5 (SCL), U4.3 (SCL)
unnamed: R3.1, U2.24 (IO47)
unnamed: U2.36 (RXD0), U5.4 (RXD)
unnamed: U2.37 (TXD0), U5.3 (TXD)

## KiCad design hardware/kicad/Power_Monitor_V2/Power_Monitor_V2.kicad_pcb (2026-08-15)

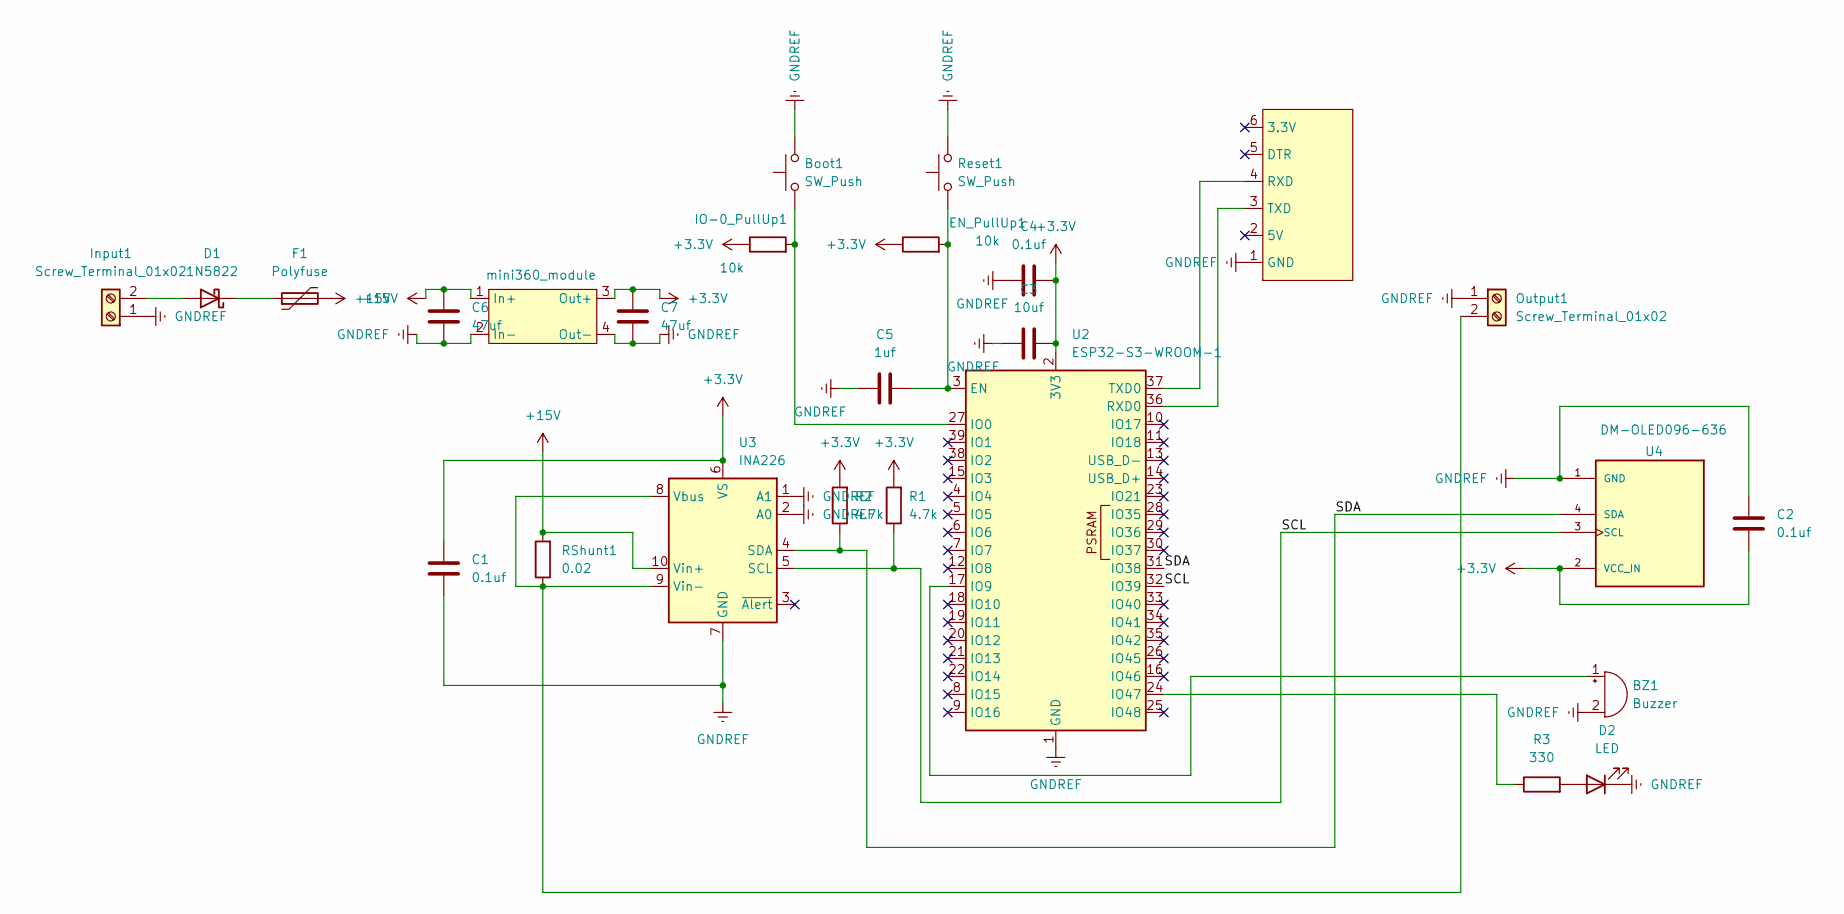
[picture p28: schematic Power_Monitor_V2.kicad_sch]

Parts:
BZ1: Buzzer; Buzzer_12x9.5RM7.6
Boot1: SW_Push; SW_Push_1P1T_NO_CK_KSC6xxG
C1, C2, C4: 0.1uf; C_0805_2012Metric_Pad1.18x1.45mm_HandSolder
C3: 10uf; C_0805_2012Metric_Pad1.18x1.45mm_HandSolder
C5: 1uf; C_0805_2012Metric_Pad1.18x1.45mm_HandSolder
C6, C7: 47uf; C_0805_2012Metric_Pad1.18x1.45mm_HandSolder
D1: 1N5822; D_DO-201AD_P15.24mm_Horizontal
D2: LED; C_0805_2012Metric_Pad1.18x1.45mm_HandSolder
EN_PullUp1: 10k; R_0603_1608Metric_Pad0.98x0.95mm_HandSolder
F1: Polyfuse; Polyfuse_Radial_L13mm_W2mm_P4.5mm_D0.8mm
IO-0_PullUp1: 10k; R_0603_1608Metric_Pad0.98x0.95mm_HandSolder
Input1: Screw_Terminal_01x02; TerminalBlock_MaiXu_MX126-5.0-02P_1x02_P5.00mm
Output1: Screw_Terminal_01x02; TerminalBlock_MaiXu_MX126-5.0-02P_1x02_P5.00mm
R1, R2: 4.7k; R_Axial_DIN0204_L3.6mm_D1.6mm_P7.62mm_Horizontal
R3: 330; R_0603_1608Metric
RShunt1: 0.02; R_Axial_DIN0204_L3.6mm_D1.6mm_P7.62mm_Horizontal
Reset1: SW_Push; SW_Push_1P1T_NO_CK_KSC6xxG
U1: mini360_module
U2: ESP32-S3-WROOM-1
U3: INA226; TSSOP-10_3x3mm_P0.5mm
U4: DM-OLED096-636; MODULE_DM-OLED096-636_PINS; PARTREV 2018-09-10
U5: PinHeader_1x06_P2.00mm_Vertical

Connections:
+3.3V: C1.1, C2.2, C3.2, C4.2, C7.1, EN_PullUp1.1, IO-0_PullUp1.1, R1.2, R2.2, U1.3 (Out+), U2.2 (3V3), U3.6 (VS), U4.2 (VCC_IN)
+15V: C6.1, F1.2, RShunt1.2, U1.1 (In+), U3.10 (Vin+)
/SCL: R1.1, U2.32 (IO39), U3.5 (SCL), U4.3 (SCL)
/SDA: R2.1, U2.31 (IO38), U3.4 (SDA), U4.4 (SDA)
GNDREF: BZ1.2 (-), Boot1.2, C1.2, C2.1, C3.1, C4.1, C5.1, C6.2, C7.2, D2.1 (K), Input1.1, Output1.1, Reset1.2, U1.2 (In-), U1.4 (Out-), U2.1 (GND), U2.40 (GND), U2.41 (GND), U3.1 (A1), U3.2 (A0), U3.7 (GND), U4.1 (GND), U5.1 (GND)
unnamed: BZ1.1 (+), U2.17 (IO9)
unnamed: D1.2 (A), Input1.2
unnamed: D1.1 (K), F1.1
unnamed: D2.2 (A), R3.2
unnamed: Output1.2, RShunt1.1, U3.8 (Vbus), U3.9 (Vin-)
unnamed: C5.2, EN_PullUp1.2, Reset1.1, U2.3 (EN)
unnamed: Boot1.1, IO-0_PullUp1.2, U2.27 (IO0)
unnamed: R3.1, U2.24 (IO47)
unnamed: U2.36 (RXD0), U5.3 (TXD)
unnamed: U2.37 (TXD0), U5.4 (RXD)

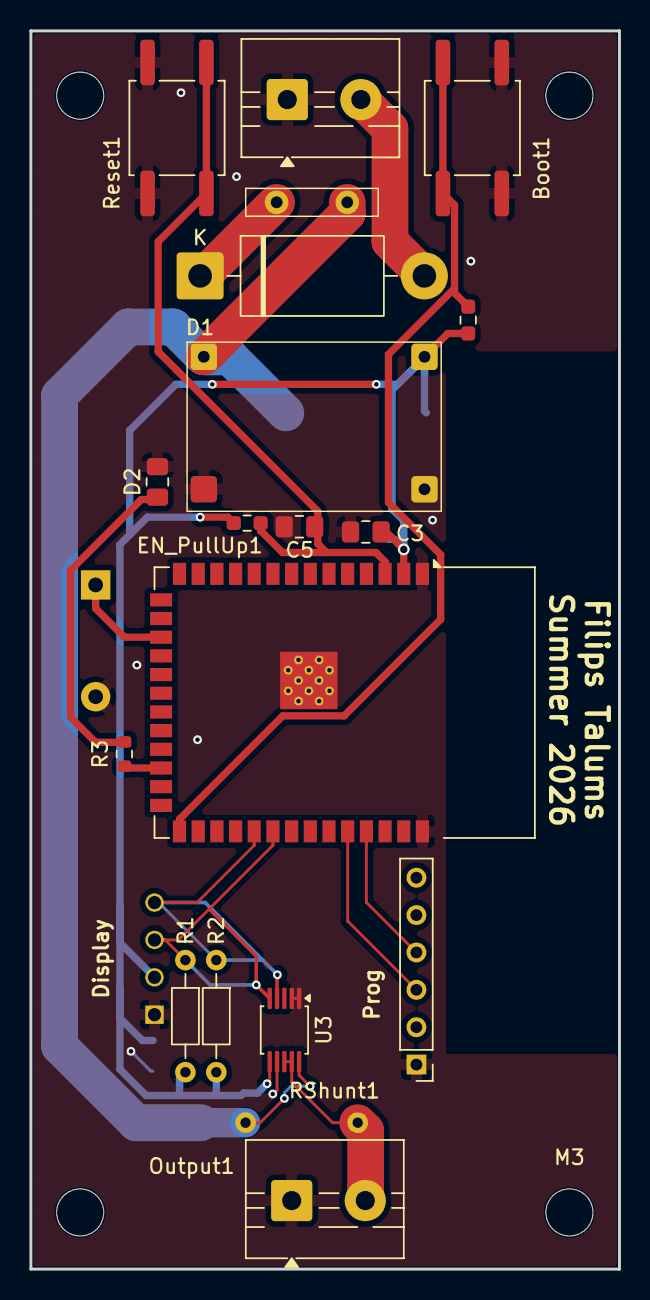
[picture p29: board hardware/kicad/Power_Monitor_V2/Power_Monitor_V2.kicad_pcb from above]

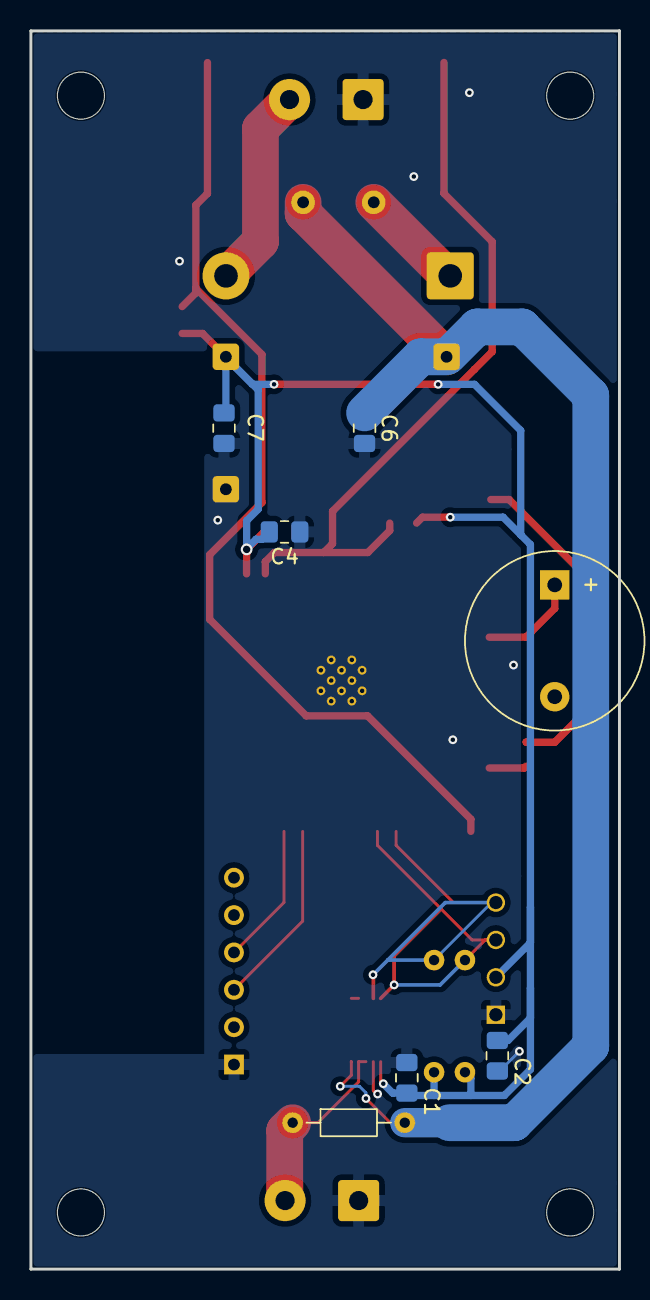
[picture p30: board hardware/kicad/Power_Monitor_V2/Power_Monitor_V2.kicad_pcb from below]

Board: 2 copper layers, 40.0 x 84.2 mm, 27 parts (7 on the bottom side), 15 nets.

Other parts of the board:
M3: MountingHole_3.2mm_M3_DIN965

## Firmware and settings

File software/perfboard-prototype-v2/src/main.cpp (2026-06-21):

#include <Arduino.h>
#include "sensor.h"
#include "config.h"
#include "oled.h"

bool displayFrozen = false;
bool lastButtonState = HIGH;

void setup() {
  Serial.begin(115200);

  bool sensorReady = initialiseSensor();

  if (!sensorReady) {
    Serial.println("Sensor Not Found");
  } else {
    Serial.println("Sensor Initialised");
  }

  initOLED();
  updateOLED();  

  pinMode(BUZZER_PIN, OUTPUT);
  pinMode(LED_PIN, OUTPUT);

  digitalWrite(BUZZER_PIN, HIGH);
  digitalWrite(LED_PIN, HIGH);

  delay(600);

  digitalWrite(BUZZER_PIN, LOW);
  digitalWrite(LED_PIN, LOW);
}



void loop() {

  updateOLED();
  

  float voltage = getBusVoltage();
  float currentA = getCurrent();
  float currentmA = currentA * 1000.0; 
  float power = getPower();

  Serial.print("Voltage (V): ");
  Serial.println(voltage);
  
  Serial.print("Current (A): ");
  Serial.println(currentA);


  Serial.print("Power   (W): ");
  Serial.println(power, 6);

  Serial.println(); 

  if (currentA >= 2){
    digitalWrite(BUZZER_PIN, HIGH);
    digitalWrite(LED_PIN, HIGH);
  }
  else{
    digitalWrite(BUZZER_PIN, LOW);
    digitalWrite(LED_PIN, LOW);
  }

  delay(1000);

  float shunt_mV = getShuntVoltage_mV();

  Serial.print("Shunt Voltage (mV): ");
  Serial.println(shunt_mV, 6);
  
  Serial.print("Current (A): ");
  Serial.println(currentA, 6);

  Serial.print("Current (mA): ");
  Serial.println(currentmA , 3);




  


}

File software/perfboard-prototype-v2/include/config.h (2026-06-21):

#pragma once

// I2C Pins
#define SCL_PIN 22
#define SDA_PIN 21

// Output Pins
#define ALERT_PIN 26 
#define BUZZER_PIN 25
#define LED_PIN 27
#define FREEZE_PIN 16

// Voltage Limits
const float MAXIMUM_VOLTAGE = 15.0;
const float MINIMUM_VOLTAGE = 5.0;

// Current Limits
const float MAXIMUM_CURRENT = 2.0;

// Battery Warning Threshold
const float WEAK_BATT_PERC = 12.5;

// Shunt Resistor
const float SHUNT_VAL = 0.1;

// Addreses

const int INA226_ADDRESS = 0x40;
const int OLED_ADDRESS = 0x3C;

// Calibration

const float VOLTAGE_CORRECTION = 0.949;
const float CURRENT_CORRECTION = 1.04;
// OLED Config

const int SCREEN_WIDTH = 128;
const int SCREEN_HEIGHT = 32;
const int text_size = .5;

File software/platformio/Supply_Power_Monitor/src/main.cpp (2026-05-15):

#include <Arduino.h>
#include "sensor.h"
#include "config.h"

void setup() {

  Serial.begin(115200);

  bool sensorReady = initialiseSensor();

  if (sensorReady == false) {
    Serial.println("Sensor Not Found");

  }

  else {
      Serial.println("Sensor Initialised");
  }
}

void loop() {

  float voltage = getBusVoltage();
  float current = getCurrent();
  float power = getPower();

  Serial.print("Voltage (V): ");
  Serial.println(voltage);
  
  Serial.print("Current (A): ");
  Serial.println(current);

  
  Serial.print("Power (W): ");
  Serial.println(power);

  Serial.println();

  delay(1000);

}

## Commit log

2026-05-09 Add design process documentation for power monitor
    Document the design process for a power monitor project, outlining project aim, problem statement, design requirements, system overview, component selection, circuit design, software design, prototype testing, calibration, problems and fixes, final design, and future improvements.
2026-05-14 Add configuration header for I2C and output pins
2026-05-23 Update description in buck_convertor_test.md
2026-05-25 Update and rename buck_convertor_test.md to buck_converter_test.md
2026-05-30 Add breadboard prototype V1 software
2026-05-30 Update calibrated breadboard prototype software
2026-05-30 Update breadboard prototype software documentation
2026-06-21 Add perfboard prototype software link
2026-08-15 Update power monitor PCB and enclosure
    [DM-OLED096-636.step, ESP-WROOM-32.step, MIni - 360.step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]
